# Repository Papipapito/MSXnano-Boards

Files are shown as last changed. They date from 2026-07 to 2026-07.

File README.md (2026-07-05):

# MSXnano · Boards

**Proof-of-concept carrier boards for the [MSXnano](https://github.com/Papipapito/MSXnano) project (Sipeed Tang Nano 20K).**
**Placas portadoras de prueba de concepto para el proyecto [MSXnano](https://github.com/Papipapito/MSXnano) (Sipeed Tang Nano 20K).**

*(English below · Español debajo)*

📄 Rich readme / readme enriquecido: [`README.html`](README.html)

### Gallery / Galería

| | |
|:---:|:---:|
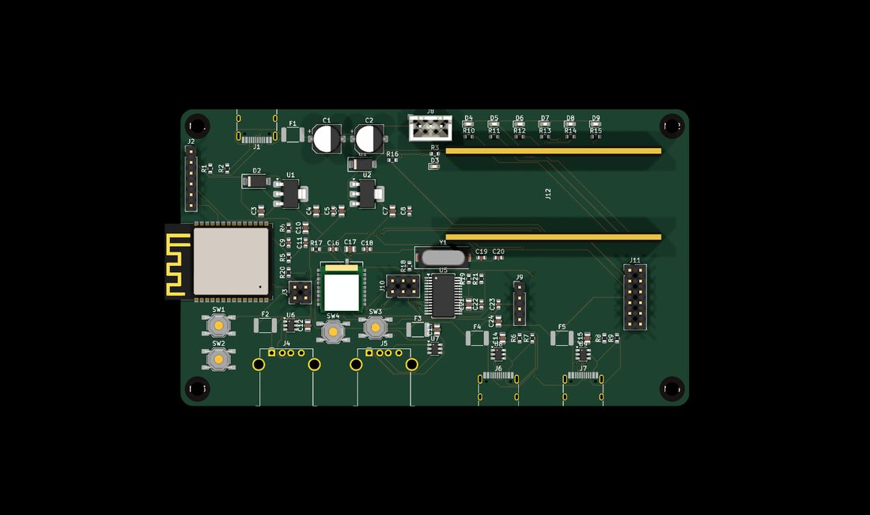
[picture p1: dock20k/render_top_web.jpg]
Top-down 3D
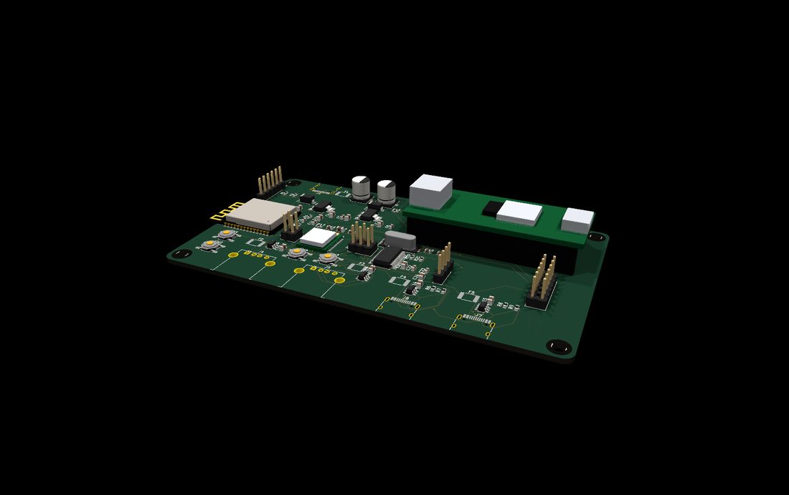
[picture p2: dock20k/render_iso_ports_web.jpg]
Assembled
|  |  |
| *Top-down 3D · Cenital 3D* | *Tang mounted on the socket · Tang montado en el zócalo* |
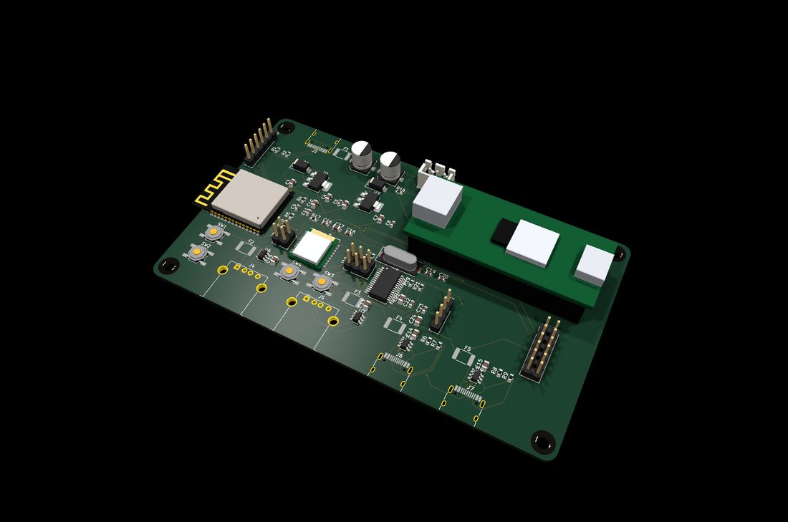
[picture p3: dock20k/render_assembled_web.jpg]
Assembled iso
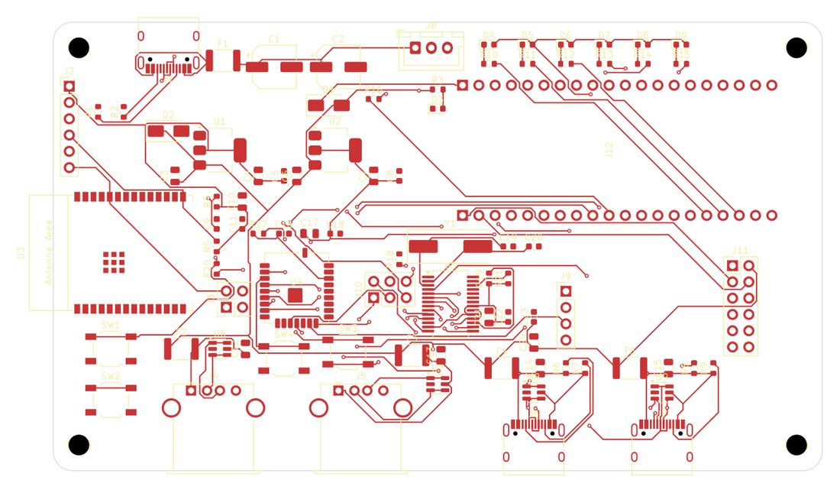
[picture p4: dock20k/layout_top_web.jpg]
KiCad top copper
|  |  |
| *Assembled · Montado* | *Top copper in KiCad (routing) · Cobre superior en KiCad (rutado)* |

More views in [`dock20k/`](dock20k/): full-res renders, front elevation, bottom copper, schematic & PCB PDFs.
*Más vistas en [`dock20k/`](dock20k/): renders a resolución completa, alzado frontal, cobre inferior, PDFs de esquemático y PCB.*

---

## 🇬🇧 English

These are **proof-of-concept boards built around the Sipeed M0S (BL616)** module. They exist for one exact reason:

> Since **~February 2024**, Sipeed ships Tang Nano 20K boards (silk-marked **`3921`**) whose **on-board BL616** has its **secure-boot eFuse in a state that often prevents it from running the FPGA-Companion firmware**. When that happens, the **USB keyboard and mouse stop working** (HDMI and the on-screen menu still work — that part is the FPGA, not the BL616). Sipeed's official workaround is to use an **external M0S Dock**.

Instead of hanging an external dock off the board with loose wires, these boards **integrate a dedicated M0S (BL616)** as the USB companion — plus a USB hub and WiFi — onto a single carrier, so **everything runs through the Tang's 2×20 headers with no external cables**.

### Boards

| Board | What it is | Status |
|---|---|---|
| [**dock20k**](dock20k/) | Tang Nano 20K carrier: **M0S (BL616)** companion + **FE1.1s** 4-port USB hub (2×USB-A + 2×USB-C) + **ESP32-C6** WiFi (UNAPI). Single USB-C power in. | Schematic ERC 0 · PCB routed (DRC 0) · **not yet fabricated** |
| [**rpi3-compatible**](rpi3-compatible/) | **Raspberry Pi 3 form factor (85×56 mm, 4-layer).** Fully modular: plug-in **Raspberry Pi Pico (RP2040)** USB companion + **ESP-01S** WiFi + **FE1.1s** hub. No soldered BL616/ESP32 — nothing exotic to source. | PCB routed (DRC 0 electrical) · **JLCPCB fab package ready** · not fabricated |

### rpi3-compatible highlights

- **Plug-in Raspberry Pi Pico (RP2040)** as the USB-HID companion, running the FPGA-Companion **`PICO`** build over the same `m0s[]` SPI path — **no RTL changes**, and it sidesteps the Tang `3921` BL616 secure-boot issue entirely (there is no on-board BL616).
- **ESP-01S** for WiFi on the core's **859372 bps** UART. Both the Pico and the ESP are **modules on sockets** — trivial to source, replace, or reflash.
- **Raspberry Pi 3 outline** (85 × 56 mm, RPi3 mounting pattern), **4 copper layers**, routed 100 % with GND planes. Ships with a **complete JLCPCB fab package** (gerbers + BOM + CPL, rotation-corrected).
- Details & key parts: [`rpi3-compatible/README.md`](rpi3-compatible/README.md).

### dock20k highlights

- **M0S (BL616)** runs the stock [FPGA-Companion](https://github.com/MiSTle-Dev/FPGA-Companion) `M0S_DOCK` build over the external `m0s[]` SPI path — **no RTL changes** to the MSXnano core.
- **ESP32-C6-WROOM-1-N8** for internet, running ducasp's [ESP32-UNAPI firmware](https://github.com/ducasp/ESP32-UNAPI-Firmware). It's the C6 (not the classic WROOM) because the core fixes the WiFi UART at **859372 bps**, a rate that is unreliable on the WROOM but fine on the C6.
- Everything routed through the **Tang's own 2×20 headers** — no external cables. Free Tang pins are broken out on an expansion header for future add-ons (e.g. MSX-MIDI).
- Connector & jumper reference: [`dock20k/CONNECTORS.md`](dock20k/CONNECTORS.md).

> ⚠️ **Proof of concept.** Designed and routed in KiCad but **not manufactured or tested in hardware yet.** Before ordering, verify the Tang socket against a physical board (rows at 20.32 mm, pin-1 position).

---

## 🇪🇸 Español

Estas son **placas de prueba de concepto construidas alrededor del módulo Sipeed M0S (BL616)**. Existen por una razón exacta:

> Desde **~febrero de 2024**, Sipeed fabrica placas Tang Nano 20K (marcadas **`3921`** en la serigrafía) cuyo **BL616 de a bordo** tiene el eFuse de **secure-boot en un estado que a menudo le impide ejecutar el firmware FPGA-Companion**. Cuando eso pasa, **el teclado y el ratón USB dejan de funcionar** (el HDMI y el menú en pantalla sí van — eso lo hace la FPGA, no el BL616). La solución oficial de Sipeed es usar un **M0S Dock externo**.

En lugar de colgar un dock externo con cables sueltos, estas placas **integran un M0S (BL616) dedicado** como companion USB —además de un hub USB y WiFi— en una sola portadora, de modo que **todo funciona por los conectores 2×20 del Tang, sin cables externos**.

### Placas

| Placa | Qué es | Estado |
|---|---|---|
| [**dock20k**](dock20k/) | Portadora del Tang Nano 20K: companion **M0S (BL616)** + hub USB **FE1.1s** de 4 puertos (2×USB-A + 2×USB-C) + WiFi **ESP32-C6** (UNAPI). Entrada única de 5 V por USB-C. | Esquemático ERC 0 · PCB rutada (DRC 0) · **sin fabricar aún** |
| [**rpi3-compatible**](rpi3-compatible/) | **Formato Raspberry Pi 3 (85×56 mm, 4 capas).** Totalmente modular: **Raspberry Pi Pico (RP2040)** enchufable como companion USB + **ESP-01S** WiFi + hub **FE1.1s**. Sin BL616/ESP32 soldados — nada raro que abastecer. | PCB rutada (DRC 0 eléctricos) · **paquete de fabricación JLCPCB listo** · sin fabricar |

### Claves de rpi3-compatible

- **Raspberry Pi Pico (RP2040) enchufable** como companion USB-HID, con el build **`PICO`** de FPGA-Companion por la misma ruta SPI `m0s[]` — **sin tocar el RTL**, y esquiva por completo el problema del secure-boot del BL616 de los Tang `3921` (aquí no hay BL616).
- **ESP-01S** para WiFi en la UART del core a **859372 bps**. Tanto el Pico como el ESP son **módulos en zócalos** — fáciles de abastecer, sustituir o reflashear.
- **Contorno Raspberry Pi 3** (85 × 56 mm, patrón de anclajes RPi3), **4 capas de cobre**, rutada al 100 % con planos de GND. Incluye un **paquete de fabricación JLCPCB completo** (gerbers + BOM + CPL, con rotaciones corregidas).
- Detalles y piezas clave: [`rpi3-compatible/README.md`](rpi3-compatible/README.md).

### Claves de dock20k

- El **M0S (BL616)** ejecuta el build `M0S_DOCK` de [FPGA-Companion](https://github.com/MiSTle-Dev/FPGA-Companion) tal cual, por la ruta SPI externa `m0s[]` — **sin tocar el RTL** del core MSXnano.
- **ESP32-C6-WROOM-1-N8** para internet, con el [firmware ESP32-UNAPI](https://github.com/ducasp/ESP32-UNAPI-Firmware) de ducasp. Es el C6 (no el WROOM clásico) porque el core fija la UART del WiFi a **859372 bps**, una velocidad poco fiable en el WROOM pero correcta en el C6.
- Todo enrutado por los **conectores 2×20 del propio Tang** — sin cables externos. Los pines libres del Tang salen a un cabezal de expansión para futuras ampliaciones (p. ej. MSX-MIDI).
- Referencia de conectores y jumpers: [`dock20k/CONNECTORS.md`](dock20k/CONNECTORS.md).

> ⚠️ **Prueba de concepto.** Diseñada y rutada en KiCad pero **aún no fabricada ni probada en hardware.** Antes de encargarla, verifica el zócalo del Tang contra una placa física (filas a 20.32 mm, posición del pin 1).

---

### Credits / Créditos

Board design: **Papipapito**. Third-party footprints/3D models (Sipeed M0S, Espressif ESP32-C6) keep their own licenses. BL616 firmware: [FPGA-Companion](https://github.com/MiSTle-Dev/FPGA-Companion) (MiSTle-Dev). WiFi firmware: [ESP32-UNAPI](https://github.com/ducasp/ESP32-UNAPI-Firmware) (ducasp).

*Diseño de la placa: **Papipapito**. Las huellas/modelos 3D de terceros conservan su licencia. Firmware BL616: FPGA-Companion. Firmware WiFi: ESP32-UNAPI de ducasp.*

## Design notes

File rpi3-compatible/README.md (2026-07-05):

# rpi3-compatible

**MSXnano carrier in Raspberry Pi 3 form factor (85 × 56 mm), fully modular.**
**Placa portadora MSXnano con formato Raspberry Pi 3 (85 × 56 mm), totalmente modular.**

Instead of soldering the USB companion and WiFi chips (like [`../dock20k`](../dock20k/)), this board takes **plug-in modules**: a **Raspberry Pi Pico (RP2040)** as the USB-HID companion and an **ESP-01S** for WiFi — so there is nothing exotic to source or reflow, and the RPi3 outline drops into any Pi-3 case/mount.

En lugar de soldar los chips de companion USB y WiFi (como en [`../dock20k`](../dock20k/)), esta placa usa **módulos enchufables**: una **Raspberry Pi Pico (RP2040)** como companion USB-HID y un **ESP-01S** para WiFi — así no hay nada raro que abastecer ni soldar, y el contorno RPi3 encaja en cualquier caja/soporte de Pi 3.

### Views / Vistas

| | |
|:---:|:---:|
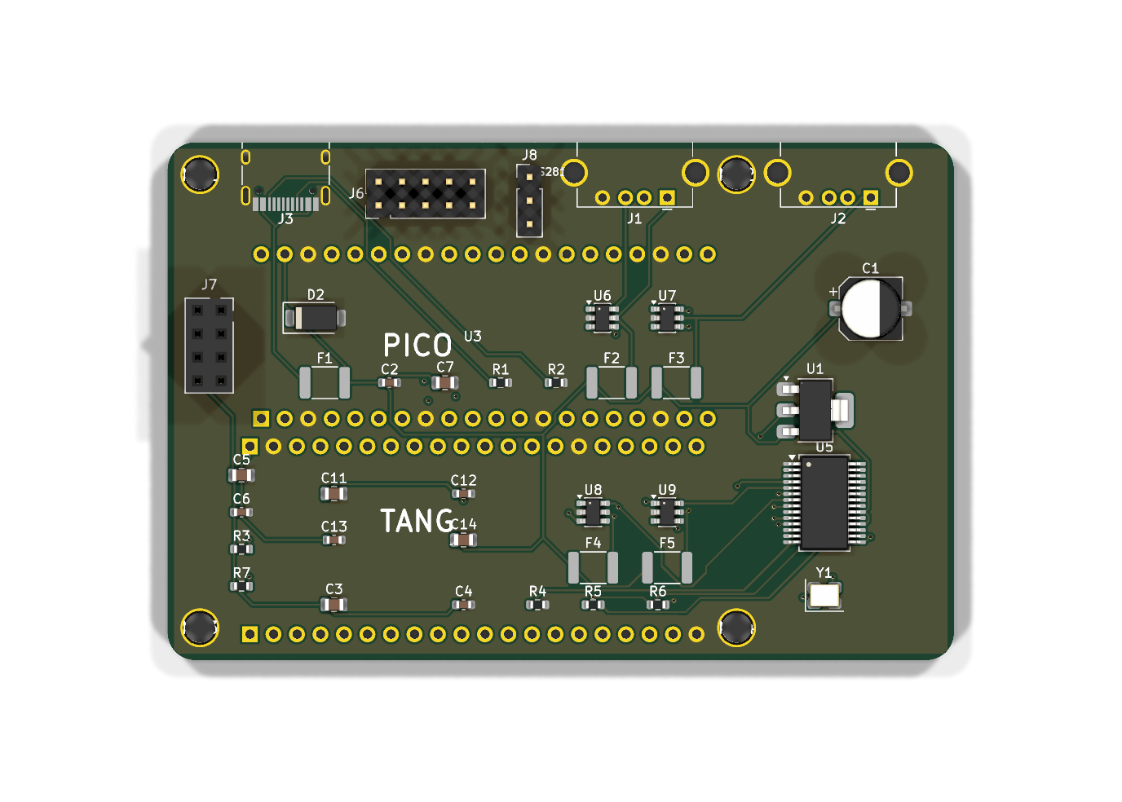
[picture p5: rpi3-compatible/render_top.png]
3D top
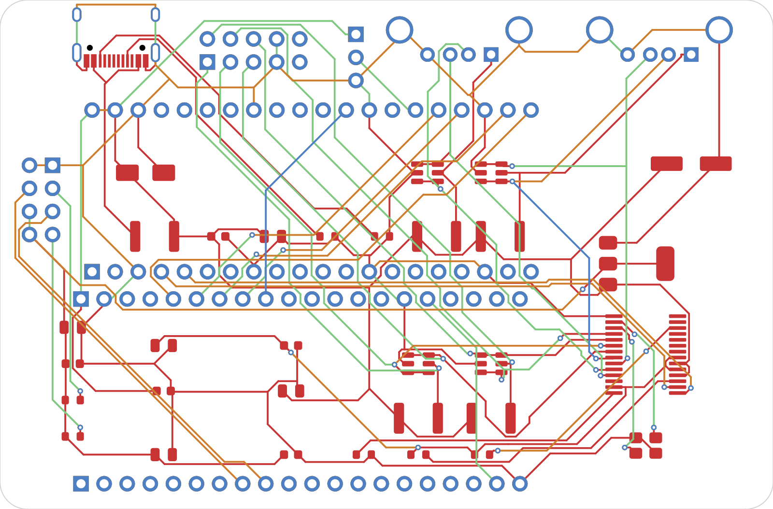
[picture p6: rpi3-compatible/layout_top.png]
Top copper
|  |  |
| *3D top (as placed) · 3D cenital (colocación real)* | *4-layer routing · Rutado 4 capas* |

PDFs: [schematic](board8020_schematic.pdf) · [PCB top](board8020_pcb_top.pdf) · 3D: [`board8020_rpi3.step`](board8020_rpi3.step)

```
USB-C 5V ──fuse 2A──► +5V ──► Tang 5V (socket) + Pico VSYS
                       ├──► AMS1117-3.3 ──► ESP-01S (WiFi)
                       └──► FE1.1s hub ──► 4 downstream ports (500 mA polyfuse each)

Tang (2x20 socket) ──SPI (M0S_* nets)──► RPi Pico (FPGA-Companion PICO build) ──USB host──► FE1.1s hub ──► 2×USB-A + USB2 header
                   ──UART 27/28──► ESP-01S UART @ 859372 bps
Pico GP20 ──► WS2812 header (J8, DIN)
```

## EN — Design notes

- **USB companion = plug-in Raspberry Pi Pico (RP2040)** on a 2×20 female socket, running the FPGA-Companion **`PICO`** build (PIO-USB host). Drives keyboard/mouse/joystick over the same SPI `m0s[]` path the core already detects — **no RTL changes**. Avoids the Tang `3921` BL616 secure-boot problem entirely (no on-board BL616 involved).
- **WiFi = ESP-01S** on a 2×4 female socket, on the core's WiFi UART @ **859372 bps** (its own 3.3 V LDO + pull-ups).
- **Hub = FE1.1s** (SSOP-28) with a **12 MHz SMD-3225 crystal** (JLC Basic C9002). Downstream: 2× USB-A on the rear edge + a **2×5 USB2 header** (2 more ports).
- **Form factor:** exact **Raspberry Pi 3** outline — 85 × 56 mm, 4 mounting holes on the RPi3 58 × 49 pattern. **4 copper layers.**
- **Header-only parts:** the USB2 header (J6), the ESP-01 socket (J7) and the **WS2812 3-pin header (J8)** are left as **plated holes** — solder your own. They are **excluded from the assembly BOM**.

## ES — Notas de diseño

- **Companion USB = Raspberry Pi Pico (RP2040) enchufable** en zócalo 2×20 hembra, con el build **`PICO`** de FPGA-Companion (host USB por PIO). Lleva teclado/ratón/joystick por la misma ruta SPI `m0s[]` que el core ya detecta — **sin tocar el RTL**. Evita por completo el problema del secure-boot del BL616 de los Tang `3921` (aquí no hay BL616).
- **WiFi = ESP-01S** en zócalo 2×4 hembra, en la UART de WiFi del core a **859372 bps** (con su LDO de 3.3 V y pull-ups).
- **Hub = FE1.1s** (SSOP-28) con **cristal 12 MHz SMD-3225** (JLC Basic C9002). Downstream: 2× USB-A en el borde trasero + un **header USB2 2×5** (2 puertos más).
- **Formato:** contorno exacto de **Raspberry Pi 3** — 85 × 56 mm, 4 anclajes en el patrón RPi3 58 × 49. **4 capas de cobre.**
- **Piezas solo-agujeros:** el header USB2 (J6), el zócalo del ESP-01 (J7) y el **header WS2812 de 3 pines (J8)** quedan como **agujeros metalizados** — los sueldas tú. Están **fuera del BOM de montaje**.

## Status / Estado

- EN: 85 × 56 mm **4-layer PCB, routed 100 %** with freerouting, GND planes on all 4 layers. **DRC: 0 unconnected, 0 electrical errors** (only cosmetic silk/library warnings). **JLCPCB fabrication package included** (gerbers + BOM + CPL). Component placement done by hand. **Not fabricated yet** — before ordering, verify the USB-A (J1/J2) and USB-C (J3) footprints/orientation and the Pico/Tang socket rows against physical modules.
- ES: PCB de **4 capas 85 × 56 mm, rutada al 100 %** con freerouting, planos de GND en las 4 capas. **DRC: 0 sin conectar, 0 errores eléctricos** (solo avisos cosméticos de serigrafía/librería). **Paquete de fabricación JLCPCB incluido** (gerbers + BOM + CPL). Colocación de componentes hecha a mano. **Sin fabricar aún** — antes de encargarla, verifica los footprints/orientación de los USB-A (J1/J2) y USB-C (J3) y las filas de los zócalos Pico/Tang contra los módulos físicos.

## Files / Ficheros

`msxnano-board8020.kicad_pro/.kicad_sch/.kicad_pcb` · `sym-lib-table` / `fp-lib-table` (paths via `${KIPRJMOD}`) · `libs/` (M0S + Espressif symbols/footprints/3D, FE1.1s + Tang/Pico sockets custom) · `board8020_schematic.pdf` · `board8020_pcb_top.pdf` · `board8020_rpi3.step` · **fab:** `board8020_gerbers.zip` · `board8020_BOM_jlcpcb.csv` · `board8020_CPL_jlcpcb.csv` (JLCPCB format, top side, rotation-corrected).

## Key parts / Piezas clave (JLCPCB LCSC)

FE1.1s hub `C9359` (SSOP-28) · AMS1117-3.3 `C6186` · USBLC6-2SC6 ESD `C2687116` ×4 · 12 MHz 3225 xtal `C9002` (Basic) · SMAJ5.0A TVS `C2925443` · USB-C `C165948` · USB-A horiz `C2345` ×2 · 10k `C98220` · 5.1k `C23186` · 2.7k `C13167` · PPTC 2A `C960026` / 500mA `C369168`. **Not assembled (holes only):** RPi Pico, Tang Nano 20K, ESP-01S socket, USB2 header, WS2812 header.

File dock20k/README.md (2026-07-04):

# dock20k

Carrier / dock board for the **Tang Nano 20K** running the **MSXnano** core.
Placa portadora ("dock") para el **Tang Nano 20K** con el core **MSXnano**.

📖 See [`CONNECTORS.md`](CONNECTORS.md) for the full connector/jumper reference · [`../README.html`](../README.html) for the illustrated bilingual overview.

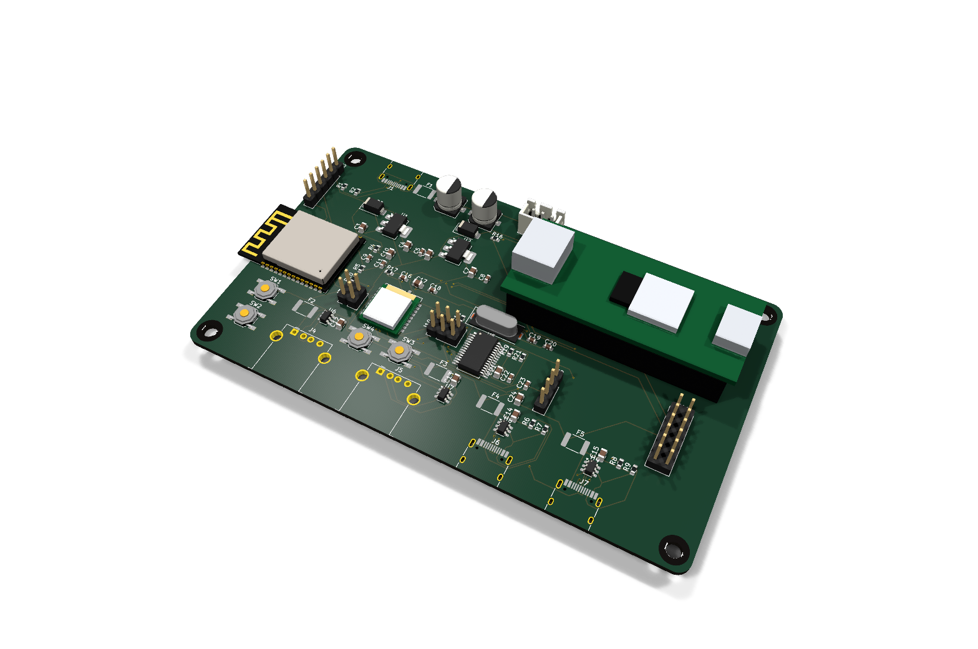
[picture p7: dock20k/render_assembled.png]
Assembled render


### Views / Vistas

| | |
|:---:|:---:|
| Top-down | Low angle |
| *Top-down 3D · Cenital 3D* | *Tang on socket · Tang en zócalo* |
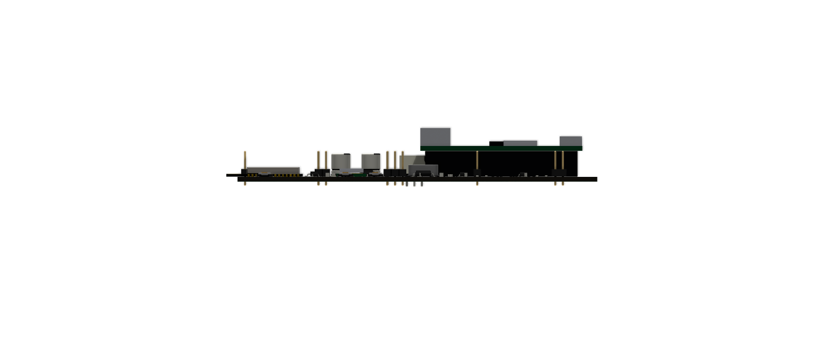
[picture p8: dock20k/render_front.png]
Front elevation
| KiCad top copper |  |
| *Top copper routing (KiCad) · Rutado cobre superior* | *Front elevation of the stack · Alzado del stack* |

Full-res: [`render_top.png`](render_top.png) · [`render_iso_ports.png`](render_iso_ports.png) · [`render_dock.png`](render_dock.png) · [`layout_top.png`](layout_top.png) · [`layout_bottom.png`](layout_bottom.png) · PDFs: [schematic](msxnano_dock_schematic.pdf) · [PCB top](msxnano_dock_pcb_top.pdf) / [bottom](msxnano_dock_pcb_bottom.pdf)

```
USB-C 5V ──fuse 2A──► +5V ──SS34──► Tang 5V pin (J5.1)
                       ├──► AMS1117-3.3 #1 ──► ESP32-C6
                       ├──► AMS1117-3.3 #2 ──► M0S / BL616
                       └──► FE1.1s hub + 4 ports (500 mA polyfuse each)

Tang (2x20 socket) ──SPI 42/41/56/54/51──► M0S BL616 ──USB──► FE1.1s hub ──► 2×USB-A + 2×USB-C
                   ──UART 27/28──► ESP32-C6 UART0 @ 859372 bps
                   ──pin 25──► WS2812   ──pins 15-20──► status LEDs   ──pin 26──► ESP reset (R20 0Ω)
```

## EN — Design notes

- **BL616 = bare Sipeed M0S module** (soldered). Runs the stock FPGA-Companion `M0S_DOCK` build — SPI on IO10–IO14 exactly like the dock, detected by the core via `m0s[2]`. No RTL changes. The M0S has **no on-board regulator** → dedicated 3.3 V LDO.
- **Hub = FE1.1s** (SSOP-28): 12 MHz crystal (load caps integrated), REXT 2.7 kΩ 1%, self-powered (BUSJ→3V3, **OVCJ→10k to 3V3, mandatory**, PWRJ NC). Note: the Rev 1.0 datasheet misprints DMU as pin 25 — it is **pin 15**.
- **WiFi = ESP32-C6-WROOM-1-N8** with ducasp's ESP32-UNAPI firmware. The core's WiFi UART is fixed at **859372 bps**; ducasp reports that rate is unreliable on the classic WROOM but fine on the C6 (the repo's default target). Needs **8 MB flash** → the -N8 part.
- **Rule:** everything goes through the Tang's two 2×20 headers — **no external cables.**

## ES — Notas de diseño

- **BL616 = módulo Sipeed M0S pelado** (soldado). Ejecuta el build `M0S_DOCK` de FPGA-Companion tal cual — SPI en IO10–IO14 igual que el dock, detectado por el core vía `m0s[2]`. Sin tocar RTL. El M0S **no lleva regulador** → LDO de 3.3 V dedicado.
- **Hub = FE1.1s** (SSOP-28): cristal 12 MHz (caps de carga integrados), REXT 2.7 kΩ 1%, self-powered (BUSJ→3V3, **OVCJ→10k a 3V3, obligatorio**, PWRJ sin conectar). Ojo: el datasheet Rev 1.0 imprime mal DMU como pin 25 — es el **pin 15**.
- **WiFi = ESP32-C6-WROOM-1-N8** con el firmware ESP32-UNAPI de ducasp. La UART del WiFi del core está fija a **859372 bps**; ducasp indica que esa velocidad es poco fiable en el WROOM clásico pero correcta en el C6 (target por defecto del repo). Necesita **8 MB de flash** → la variante -N8.
- **Regla:** todo pasa por los dos conectores 2×20 del Tang — **sin cables externos.**

## Status / Estado

- EN: Schematic complete (**ERC 0 errors**). 2-layer PCB, **routed 100%** with freerouting (**DRC 0 errors**), GND pours both sides, RF keepout under the ESP antenna. **Not fabricated yet** — verify the socket against a real Tang (rows 20.32 mm, pin-1 side) before ordering.
- ES: Esquemático completo (**ERC 0 errores**). PCB de 2 capas, **rutada al 100%** con freerouting (**DRC 0 errores**), planos de GND en ambas caras, keepout de RF bajo la antena del ESP. **Sin fabricar aún** — verifica el zócalo contra un Tang real (filas 20.32 mm, lado del pin 1) antes de encargarla.

## Files / Ficheros

`msxnano_dock.kicad_pro/.kicad_sch/.kicad_pcb` · `sym-lib-table` / `fp-lib-table` (paths via `${KIPRJMOD}`) · `libs/` (M0S + Espressif official symbols/footprints/3D, FE1.1s + Tang socket custom) · `msxnano_dock_schematic.pdf` · `msxnano_dock_pcb_top.pdf` / `_bottom.pdf` · `msxnano_dock_bom.csv` · `render_dock.png` / `render_assembled.png`

## Sources / Fuentes (verified 2026-07)

Tang Nano 20K official 3921 schematic + dimensions (dl.sipeed.com) · M0S module & dock schematics + official KiCad footprint · FE1.1s datasheet Rev B (DMU = pin 15) · ESP32-UNAPI source (UART0, baud, 8 MB, targets).

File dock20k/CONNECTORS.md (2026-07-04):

# dock20k — Connectors / Conectores (J1–J12)

Reference for every connector and jumper: what it is, its pinout and what to use it for.
Reader-friendly HTML version: [`../README.html`](../README.html).

Referencia de todos los conectores y jumpers: qué son, su pinout y para qué usarlos.
Versión HTML más cómoda de leer: [`../README.html`](../README.html).

> Pin numbers match the PCB silkscreen (pin 1 has a square pad). On 2-row connectors,
> the odd column is 1/3/5… and the even column is 2/4/6….
> **[cap]** = a 2.54 mm jumper. "Bridge A-B" = place a cap over pins A and B.
>
> Los números de pin coinciden con la serigrafía (el pin 1 lleva pad cuadrado). En los
> conectores de 2 filas, la columna impar es 1/3/5… y la par 2/4/6….
> **[cap]** = puente de 2.54 mm. "Puentear A-B" = colocar un cap sobre los pines A y B.

---

## Summary / Resumen

| Ref | Silk | Type / Tipo | Use / Uso | Jumper? |
|-----|---|---|---|---|
| **J1**  | USB-C_POWER | USB-C recept. | 5 V power in / entrada 5 V (+ BL616 flash data) | — |
| **J2**  | ESP_FLASH | 1×6 header | Program the ESP32-C6 / programar el ESP32-C6 | — |
| **J3**  | ESP_UART_LINK | 2×2 | Connect/isolate FPGA↔ESP UART / conectar-aislar UART | **Yes (2)** |
| **J4**  | USB-A_1 | USB-A recept. | USB output port / puerto USB de salida | — |
| **J5**  | USB-A_2 | USB-A recept. | USB output port / puerto USB de salida | — |
| **J6**  | USB-C_1 | USB-C recept. | USB output port / puerto USB de salida | — |
| **J7**  | USB-C_2 | USB-C recept. | USB output port / puerto USB de salida | — |
| **J8**  | WS2812_STRIP  | JST-XH 1×3 | WS2812 LED strip / tira de LEDs WS2812 | — |
| **J9**  | BL616_FLASH | 1×4 header | BL616 serial log + emergency flash | — |
| **J10** | BL_USB_SEL | 2×3 | Route BL616 USB: hub vs flash / enrutar USB del BL616 | **Yes (2)** |
| **J11** | EXPANSION | 2×6 | Free Tang pins + power / pines libres del Tang | — |
| **J12** | TangNano20K | 2×20 socket | Where the Tang plugs in / donde se enchufa el Tang | — |

Buttons / Pulsadores: **SW1** = ESP reset, **SW2** = ESP boot, **SW3** = BL616 boot, **SW4** = BL616 reset.

---

## The two config jumpers / Los dos jumpers de configuración

### J3 — ESP_UART_LINK (FPGA ↔ ESP32 serial link / enlace serie)

```
 row1   1 FPGA_TX  ──  2 ESP_RX0     [cap 1-2]
 row2   3 ESP_TX0  ──  4 FPGA_RX     [cap 3-4]
```

- **EN — Normal (WiFi working):** both caps on (1-2 and 3-4). ESP and core talk at 859372 bps.
  **To flash the ESP:** remove both caps, so the FPGA lines don't fight the USB-serial adapter on J2.
- **ES — Normal (WiFi funcionando):** los dos caps puestos (1-2 y 3-4). ESP y core hablan a 859372 bps.
  **Para flashear el ESP:** quita los dos caps, para que las líneas de la FPGA no peleen con el adaptador USB-serie de J2.

### J10 — BL_USB_SEL (where the BL616's single USB goes / a dónde va el único USB del BL616)

```
          D+ column        D- column
 row1   1 HUB_UP_DP      2 HUB_UP_DM     → to the USB hub (normal / normal)
 row2   3 BL_USB_DP      4 BL_USB_DM     → BL616 USB (common / común)
 row3   5 PC_DP          6 PC_DM         → J1 data lines (flashing / flasheo)
```

- **EN — Normal (keyboard/mouse via hub):** caps on **1-3 and 2-4** (BL616 → hub). Default position.
  **To flash the BL616:** move caps to **3-5 and 4-6** (BL616 → J1), then plug a USB-C **data** cable from J1 to the PC.
- **ES — Normal (teclado/ratón por el hub):** caps en **1-3 y 2-4** (BL616 → hub). Posición por defecto.
  **Para flashear el BL616:** mueve los caps a **3-5 y 4-6** (BL616 → J1), y conecta un cable USB-C **de datos** de J1 al PC.

---

## Programming headers / Cabeceras de programación

### J2 — ESP_FLASH (1×6) — program the ESP32-C6 / programar el ESP32-C6

```
 1  +3V3   ESP logic (don't connect if already USB-C powered) / lógica del ESP (no conectar si ya alimentas por USB-C)
 2  GND
 3  EN     ESP reset  → adapter RTS (or SW1) / reset del ESP → RTS (o SW1)
 4  BOOT   GPIO9      → adapter DTR (or SW2) / arranque → DTR (o SW2)
 5  TX0    GPIO16     → adapter RX
 6  RX0    GPIO17     → adapter TX
```
Remove J3 caps before flashing here. / Quita los caps de J3 antes de flashear por aquí.
After the first flash, the firmware updates over WiFi (OTA) or via the MSX link.
Tras el primer flasheo, el firmware se actualiza por WiFi (OTA) o por el enlace MSX.

### J9 — BL616_FLASH (1×4) — log + emergency flash / log + flasheo de emergencia

```
 1  +3V3
 2  GND
 3  TX     BL616 GPIO21  → adapter RX   (serial log 115200 8N1 / log serie 115200 8N1)
 4  RX     BL616 GPIO22  → adapter TX
```

---

## Power & outputs / Alimentación y salidas

- **J1 — USB-C_POWER.** EN: powers the whole board and the Tang (via its 5 V pin, through an SS34 blocking diode); its data lines feed J10 (used only when flashing the BL616). · ES: alimenta toda la placa y el Tang (por su pin de 5 V, con diodo SS34 anti-retorno); sus líneas de datos van a J10 (solo se usan al flashear el BL616).
- **J4 / J5 (USB-A) · J6 / J7 (USB-C).** EN: the four USB output ports of the FE1.1s hub — keyboard, mouse, joypad, flash drive. Each has a 500 mA polyfuse + ESD. USB-C ports act as host (56 k Rp). · ES: los cuatro puertos USB de salida del hub FE1.1s — teclado, ratón, joypad, pendrive. Cada uno con polyfuse de 500 mA + ESD. Los USB-C actúan como host (Rp 56 k).
- **J8 — WS2812_STRIP (JST 1×3):** `1=+5V, 2=DIN (Tang pin 25 via 330 Ω), 3=GND`. EN: addressable LED strip (case). · ES: tira de LEDs direccionables (caja).

### J11 — EXPANSION (2×6) — free Tang pins / pines libres del Tang

```
 odd column (left)      even column (right)
 1  3V3 (Tang)          2  +5V
 3  P73                 4  P74
 5  P77                 6  P29
 7  P30                 8  P31
 9  P72                10  P71
11  GND                12  GND
```
EN: unused FPGA balls + power, for future add-ons (e.g. MSX-MIDI) without redesigning the board. Assign a new signal in the core's `.cst` to one of these pins.
ES: balls de la FPGA sin usar + alimentación, para ampliaciones futuras (p. ej. MSX-MIDI) sin rediseñar la placa. Asigna la señal nueva en el `.cst` del core a uno de estos pines.

### J12 — TangNano20K socket / zócalo

EN: not a jumper — the 2×20 **female socket where the Tang Nano 20K plugs in**. Every signal between board and Tang passes through here (no loose wires). Rows 20.32 mm apart; row A is the 5 V side (per official 3921 schematic).
ES: no es un jumper — el **zócalo 2×20 hembra donde se enchufa el Tang Nano 20K**. Todas las señales entre placa y Tang pasan por aquí (sin cables sueltos). Filas a 20.32 mm; la fila A es la del pin de 5 V (según el esquemático oficial 3921).

---

## Recipes / Recetas

**1) Normal operation / Funcionamiento normal** — J3: both caps (1-2, 3-4) · J10: caps up (1-3, 2-4) · Tang in J12, power on J1, peripherals on J4–J7.

**2) Flash the ESP32-C6 / Flashear el ESP32-C6** — remove J3 caps · USB-UART on J2 (TX↔RX crossed) · hold **SW2 BOOT** + press **SW1 RST** · program, then restore J3 caps.

**3) Flash the BL616 / Flashear el BL616** — J10 caps to 3-5, 4-6 · USB-C data cable J1→PC · hold **SW3 BL_BOOT** + press **SW4 BL_RST** · load `fpga_companion_m0sdock.bin`, then restore J10 caps. (Alt: UART on J9.)

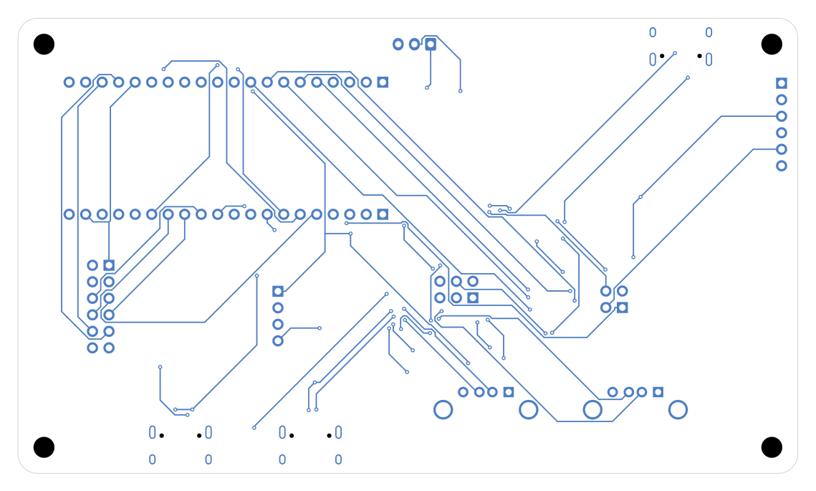
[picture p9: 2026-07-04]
dock20k/layout_bottom.png

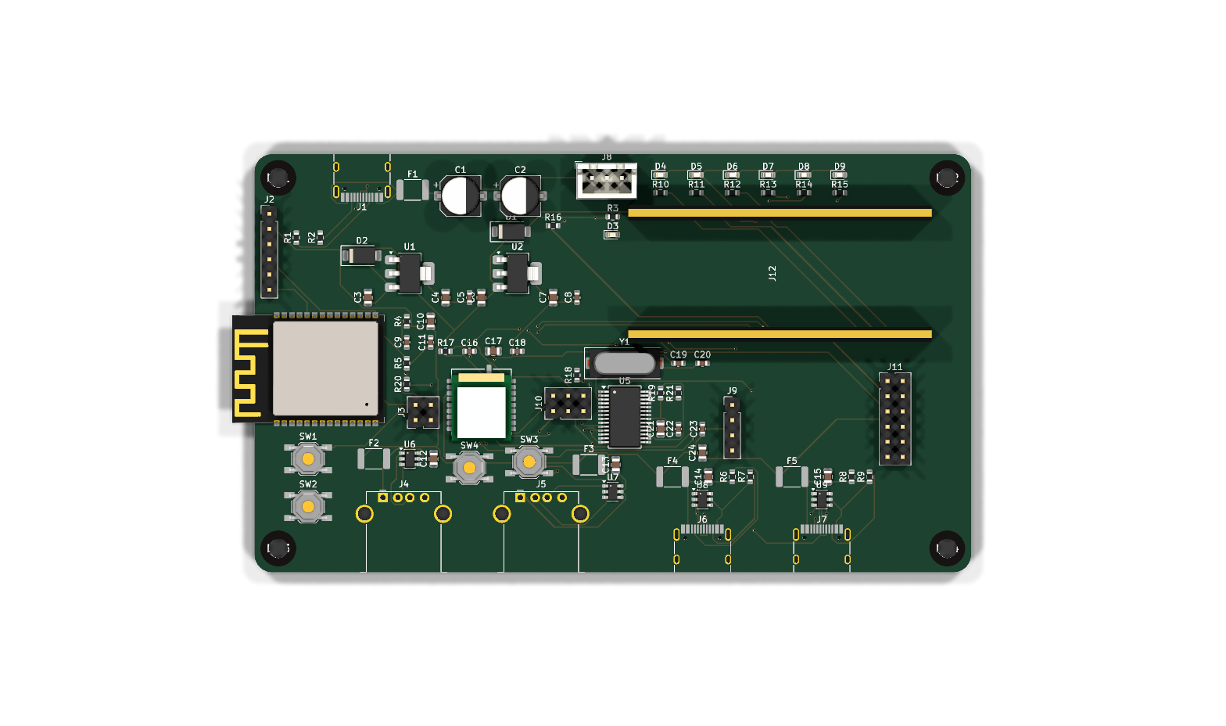
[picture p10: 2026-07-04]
dock20k/render_top.png

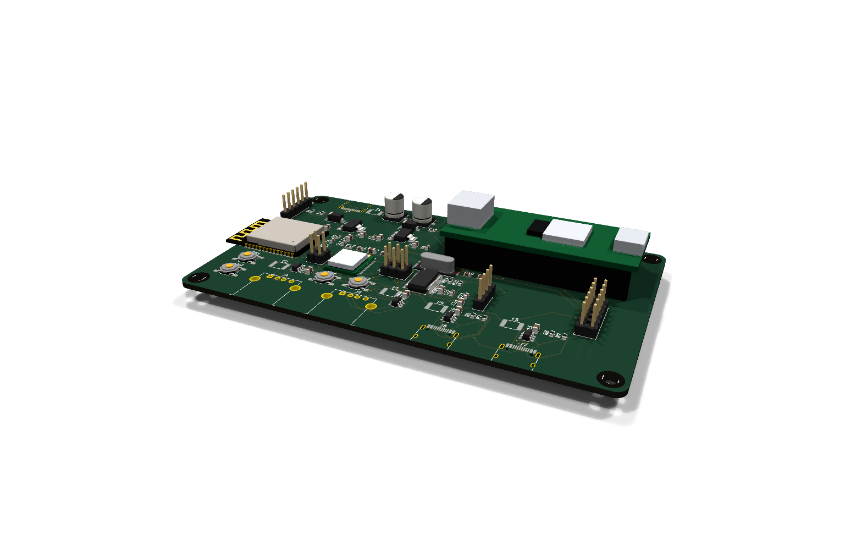
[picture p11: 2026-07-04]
dock20k/render_iso_ports.png

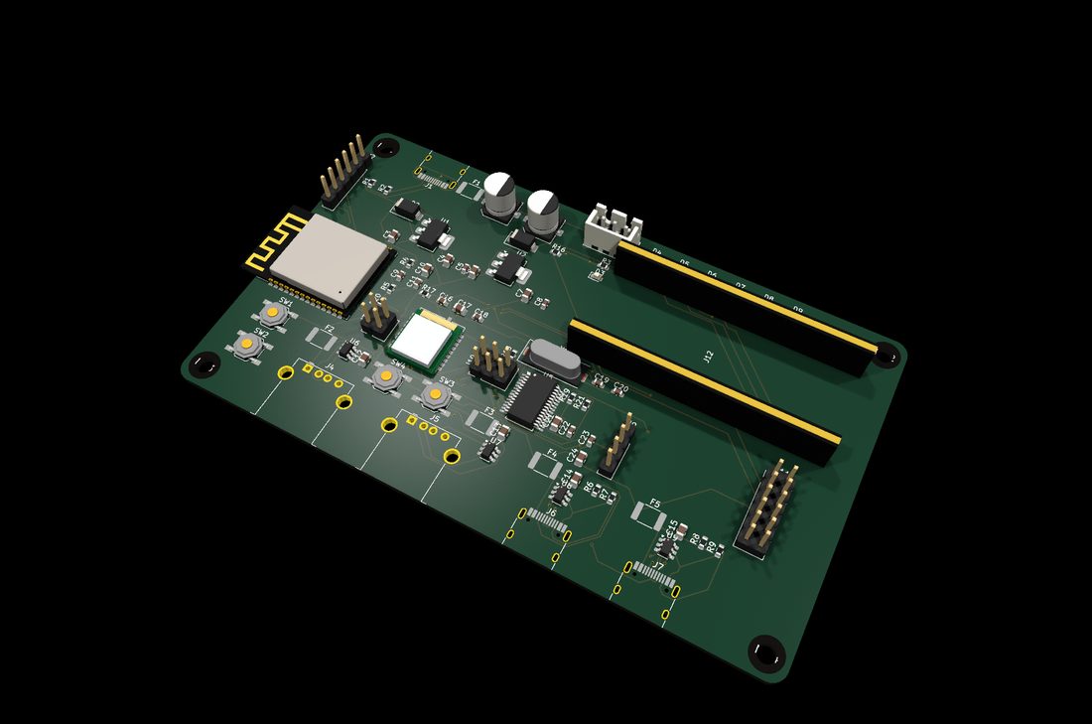
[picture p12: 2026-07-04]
dock20k/render_dock_web.jpg

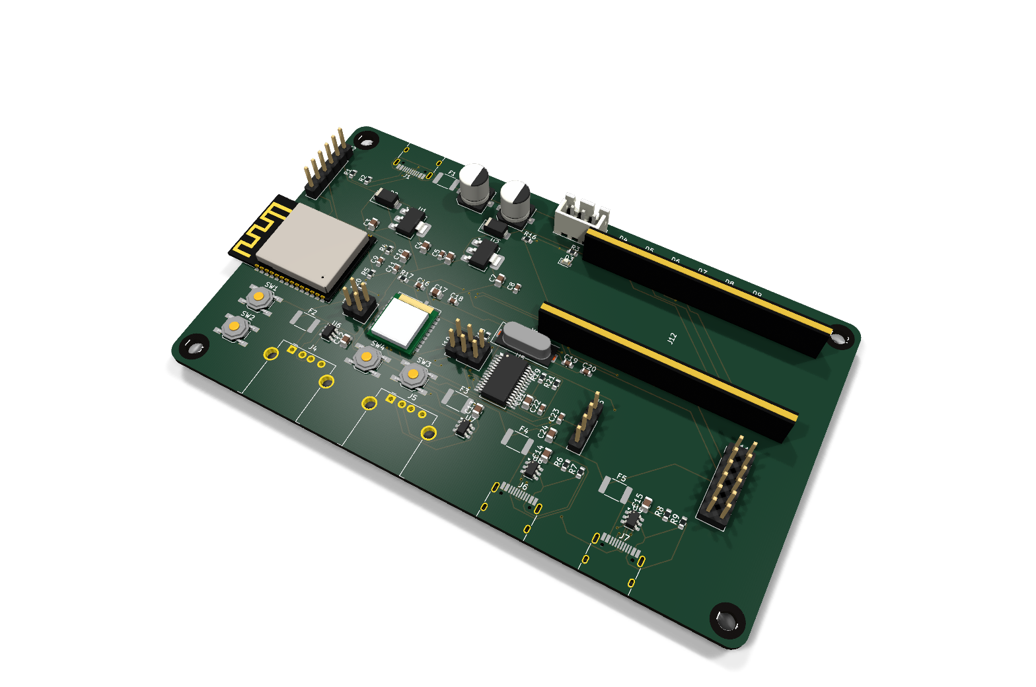
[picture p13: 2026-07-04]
dock20k/render_dock.png

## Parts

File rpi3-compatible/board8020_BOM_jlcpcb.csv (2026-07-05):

Comment | Designator | Footprint | LCSC Part #
5.1k 0603 1% | R1,R2 | R_0603 | C23186
10k 0603 1% | R3,R5,R6,R7 | R_0603 | C98220
2.7k 0603 1% | R4 | R_0603 | C13167
100nF 50V 0603 | C2,C4,C6,C12,C13 | C_0603 | C14663
10uF 25V 0805 | C5,C7,C11,C14 | C_0805 | C15850
22uF 25V 0805 | C3 | C_0805 | C45783
220uF 25V | C1 | CP_Elec_6.3x7.7 | C2918361
12MHz | Y1 | Crystal_SMD_3225-4Pin | C9002
AMS1117-3.3 | U1 | SOT-223 | C6186
FE1.1S | U5 | SSOP-28 | C9359
USBLC6-2SC6 | U6,U7,U8,U9 | SOT-23-6 | C2687116
SMAJ5.0A | D2 | D_SMA | C2925443
PPTC 2A | F1 | Fuse_1812 | C960026
PPTC 500mA | F2,F3,F4,F5 | Fuse_1812 | C369168
USB-C TYPE-C-31-M-12 | J3 | USB_C_HRO | C165948
USB-A hembra horiz 902-131A | J1,J2 | USB_A_horiz | C2345

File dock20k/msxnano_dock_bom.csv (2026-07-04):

value | footprint | quantity | references
12MHz | Crystal:Crystal_SMD_HC49-SD | 1 | ['Y1']
MountingHole_3.2mm | MountingHole:MountingHole_3.2mm | 4 | ['MH4', 'MH1', 'MH3', 'MH2']
LED2 | LED_SMD:LED_0603_1608Metric | 1 | ['D6']
1k | Resistor_SMD:R_0603_1608Metric | 7 | ['R17', 'R14', 'R11', 'R10', 'R13', 'R12', 'R15']
SS34 | Diode_SMD:D_SMA | 1 | ['D1']
EXPANSION | Connector_PinHeader_2.54mm:PinHeader_2x06_P2.54mm_Vertical | 1 | ['J11']
BL_USB_SEL | Connector_PinHeader_2.54mm:PinHeader_2x03_P2.54mm_Vertical | 1 | ['J10']
18pF (DNP) | Capacitor_SMD:C_0603_1608Metric | 2 | ['C19', 'C20']
2A | Fuse:Fuse_1812_4532Metric | 1 | ['F1']
330R | Resistor_SMD:R_0603_1608Metric | 1 | ['R16']
220uF/10V | Capacitor_SMD:CP_Elec_6.3x7.7 | 2 | ['C1', 'C2']
10uF | Capacitor_SMD:C_0805_2012Metric | 9 | ['C21', 'C13', 'C3', 'C15', 'C24', 'C12', 'C6', 'C14', 'C17']
ESP_RST | Button_Switch_SMD:SW_SPST_TL3342 | 1 | ['SW1']
22uF | Capacitor_SMD:C_0805_2012Metric | 3 | ['C10', 'C7', 'C4']
ESP_BOOT | Button_Switch_SMD:SW_SPST_TL3342 | 1 | ['SW2']
5k1 | Resistor_SMD:R_0603_1608Metric | 2 | ['R1', 'R2']
100nF | Capacitor_SMD:C_0603_1608Metric | 7 | ['C8', 'C16', 'C23', 'C22', 'C11', 'C18', 'C5']
SMAJ5.0A | Diode_SMD:D_SMA | 1 | ['D2']
56k | Resistor_SMD:R_0603_1608Metric | 4 | ['R9', 'R7', 'R6', 'R8']
LED1 | LED_SMD:LED_0603_1608Metric | 1 | ['D5']
LED3 | LED_SMD:LED_0603_1608Metric | 1 | ['D7']
FE1.1s | Package_SO:SSOP-28_5.3x10.2mm_P0.65mm | 1 | ['U5']
BL_RST | Button_Switch_SMD:SW_SPST_TL3342 | 1 | ['SW4']
TangNano20K | msxnano_dock:TangNano20K_Socket | 1 | ['J12']
PWR | LED_SMD:LED_0603_1608Metric | 1 | ['D3']
LED5 | LED_SMD:LED_0603_1608Metric | 1 | ['D9']
10k | Resistor_SMD:R_0603_1608Metric | 4 | ['R19', 'R4', 'R5', 'R21']
BL_BOOT | Button_Switch_SMD:SW_SPST_TL3342 | 1 | ['SW3']
USB-A_1 | Connector_USB:USB_A_Stewart_SS-52100-001_Horizontal | 1 | ['J4']
500mA | Fuse:Fuse_1812_4532Metric | 4 | ['F2', 'F5', 'F3', 'F4']
0R | Resistor_SMD:R_0603_1608Metric | 1 | ['R20']
USB-C_2 | Connector_USB:USB_C_Receptacle_HRO_TYPE-C-31-M-12 | 1 | ['J7']
LED4 | LED_SMD:LED_0603_1608Metric | 1 | ['D8']
USBLC6-2SC6 | Package_TO_SOT_SMD:SOT-23-6 | 4 | ['U7', 'U6', 'U9', 'U8']
USB-C_1 | Connector_USB:USB_C_Receptacle_HRO_TYPE-C-31-M-12 | 1 | ['J6']
2k7 1% | Resistor_SMD:R_0603_1608Metric | 1 | ['R18']
LED0 | LED_SMD:LED_0603_1608Metric | 1 | ['D4']
WS2812_STRIP | Connector_JST:JST_XH_B3B-XH-A_1x03_P2.50mm_Vertical | 1 | ['J8']
USB-A_2 | Connector_USB:USB_A_Stewart_SS-52100-001_Horizontal | 1 | ['J5']
USB-C_POWER | Connector_USB:USB_C_Receptacle_HRO_TYPE-C-31-M-12 | 1 | ['J1']
1uF | Capacitor_SMD:C_0603_1608Metric | 1 | ['C9']
BL616_FLASH | Connector_PinHeader_2.54mm:PinHeader_1x04_P2.54mm_Vertical | 1 | ['J9']
ESP_FLASH | Connector_PinHeader_2.54mm:PinHeader_1x06_P2.54mm_Vertical | 1 | ['J2']
AMS1117-3.3 | Package_TO_SOT_SMD:SOT-223-3_TabPin2 | 2 | ['U2', 'U1']
ESP_UART_LINK | Connector_PinHeader_2.54mm:PinHeader_2x02_P2.54mm_Vertical | 1 | ['J3']
2k2 | Resistor_SMD:R_0603_1608Metric | 1 | ['R3']
ESP32-C6-WROOM-1-N8 | msxnano_dock:ESP32-C6-WROOM-1 | 1 | ['U3']
Sipeed_M0S_BL616 | msxnano_dock:M0S | 1 | ['U4']

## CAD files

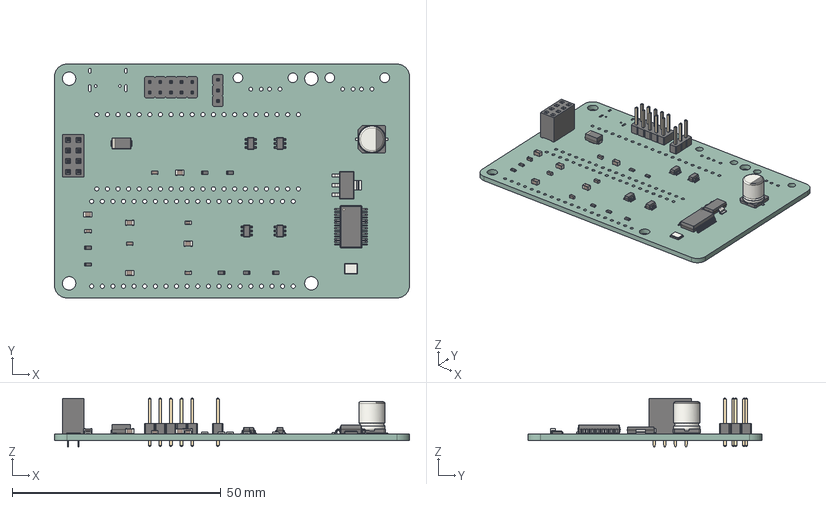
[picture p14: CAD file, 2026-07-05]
rpi3-compatible/board8020_rpi3.step
85.0 x 56.0 x 11.6 mm
R_0603_1608Metric x 7
C_0603_1608Metric x 5
SOT-23-6 x 4
C_0805_2012Metric x 5
CP_Elec_63x77
PinHeader_2x05_P254mm_Vertical
SOT-223
PinHeader_1x03_P254mm_Vertical
PinSocket_2x04_P2.54mm_Vertical
D_SMA
SSOP-28_5.3x10.2mm_P0.65mm
Crystal_SMD_3225-4Pin_3.2x2.5mm
msxnano-board8020_PCB

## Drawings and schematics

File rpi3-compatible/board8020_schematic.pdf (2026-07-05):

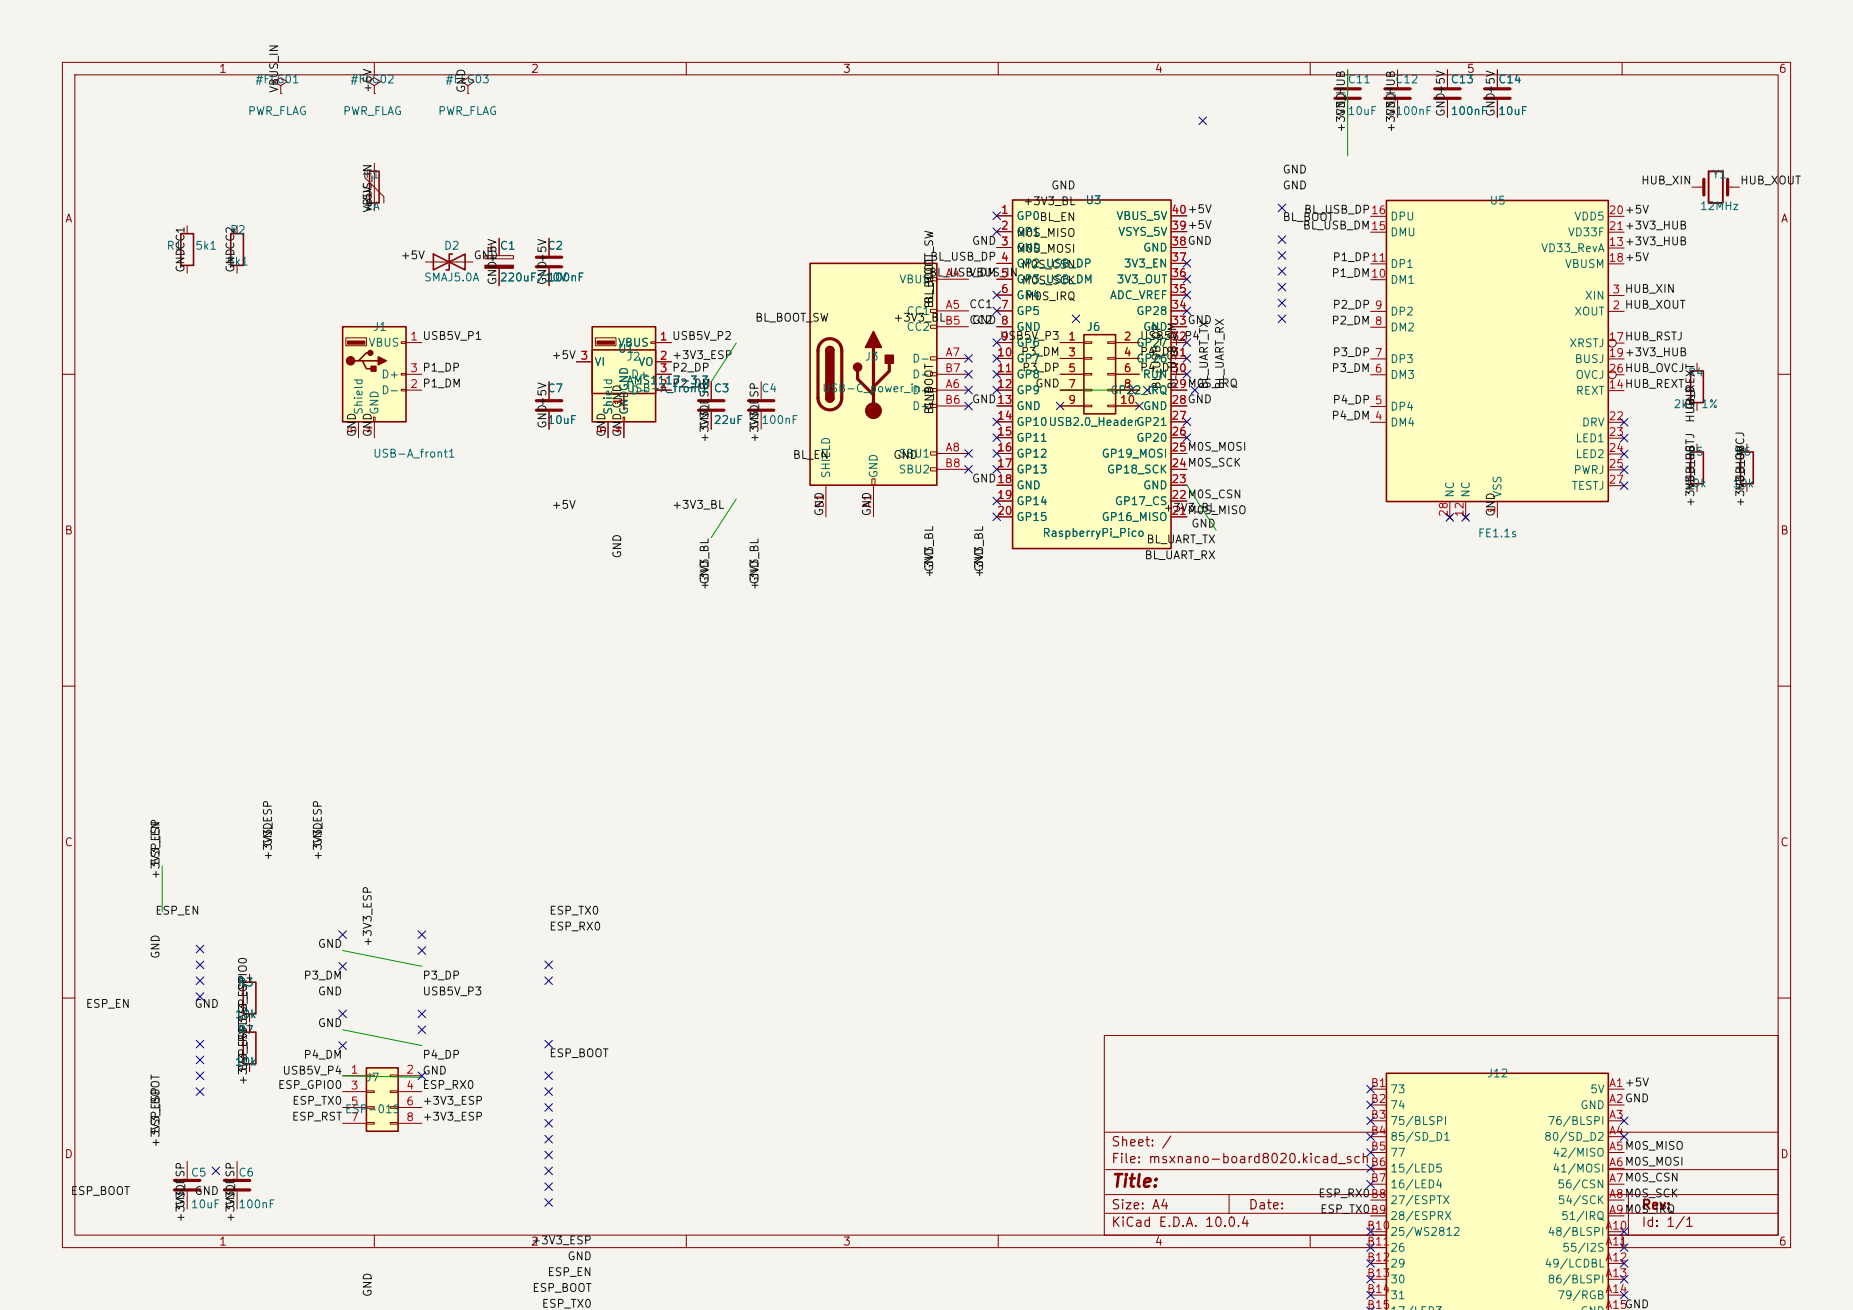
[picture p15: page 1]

Sheet: / File: msxnano-board8020.kicad_sch | 77 B5 42/MISO A5 15/LED5 B6 41/MOSI A6 | | D Date:

Title: | 16/LED4 B7 56/CSN A7
Size: A4 | ESP_TX0 | 27/ESPTX B8 54/SCK A8 28/ESPRX B9 51/IRQ A9 | M0S_IRQ | Rev:

KiCad E.D.A. 10.0.4 | | 25/WS2812 B10 48/BLSPIA10 | | Id: 1/1

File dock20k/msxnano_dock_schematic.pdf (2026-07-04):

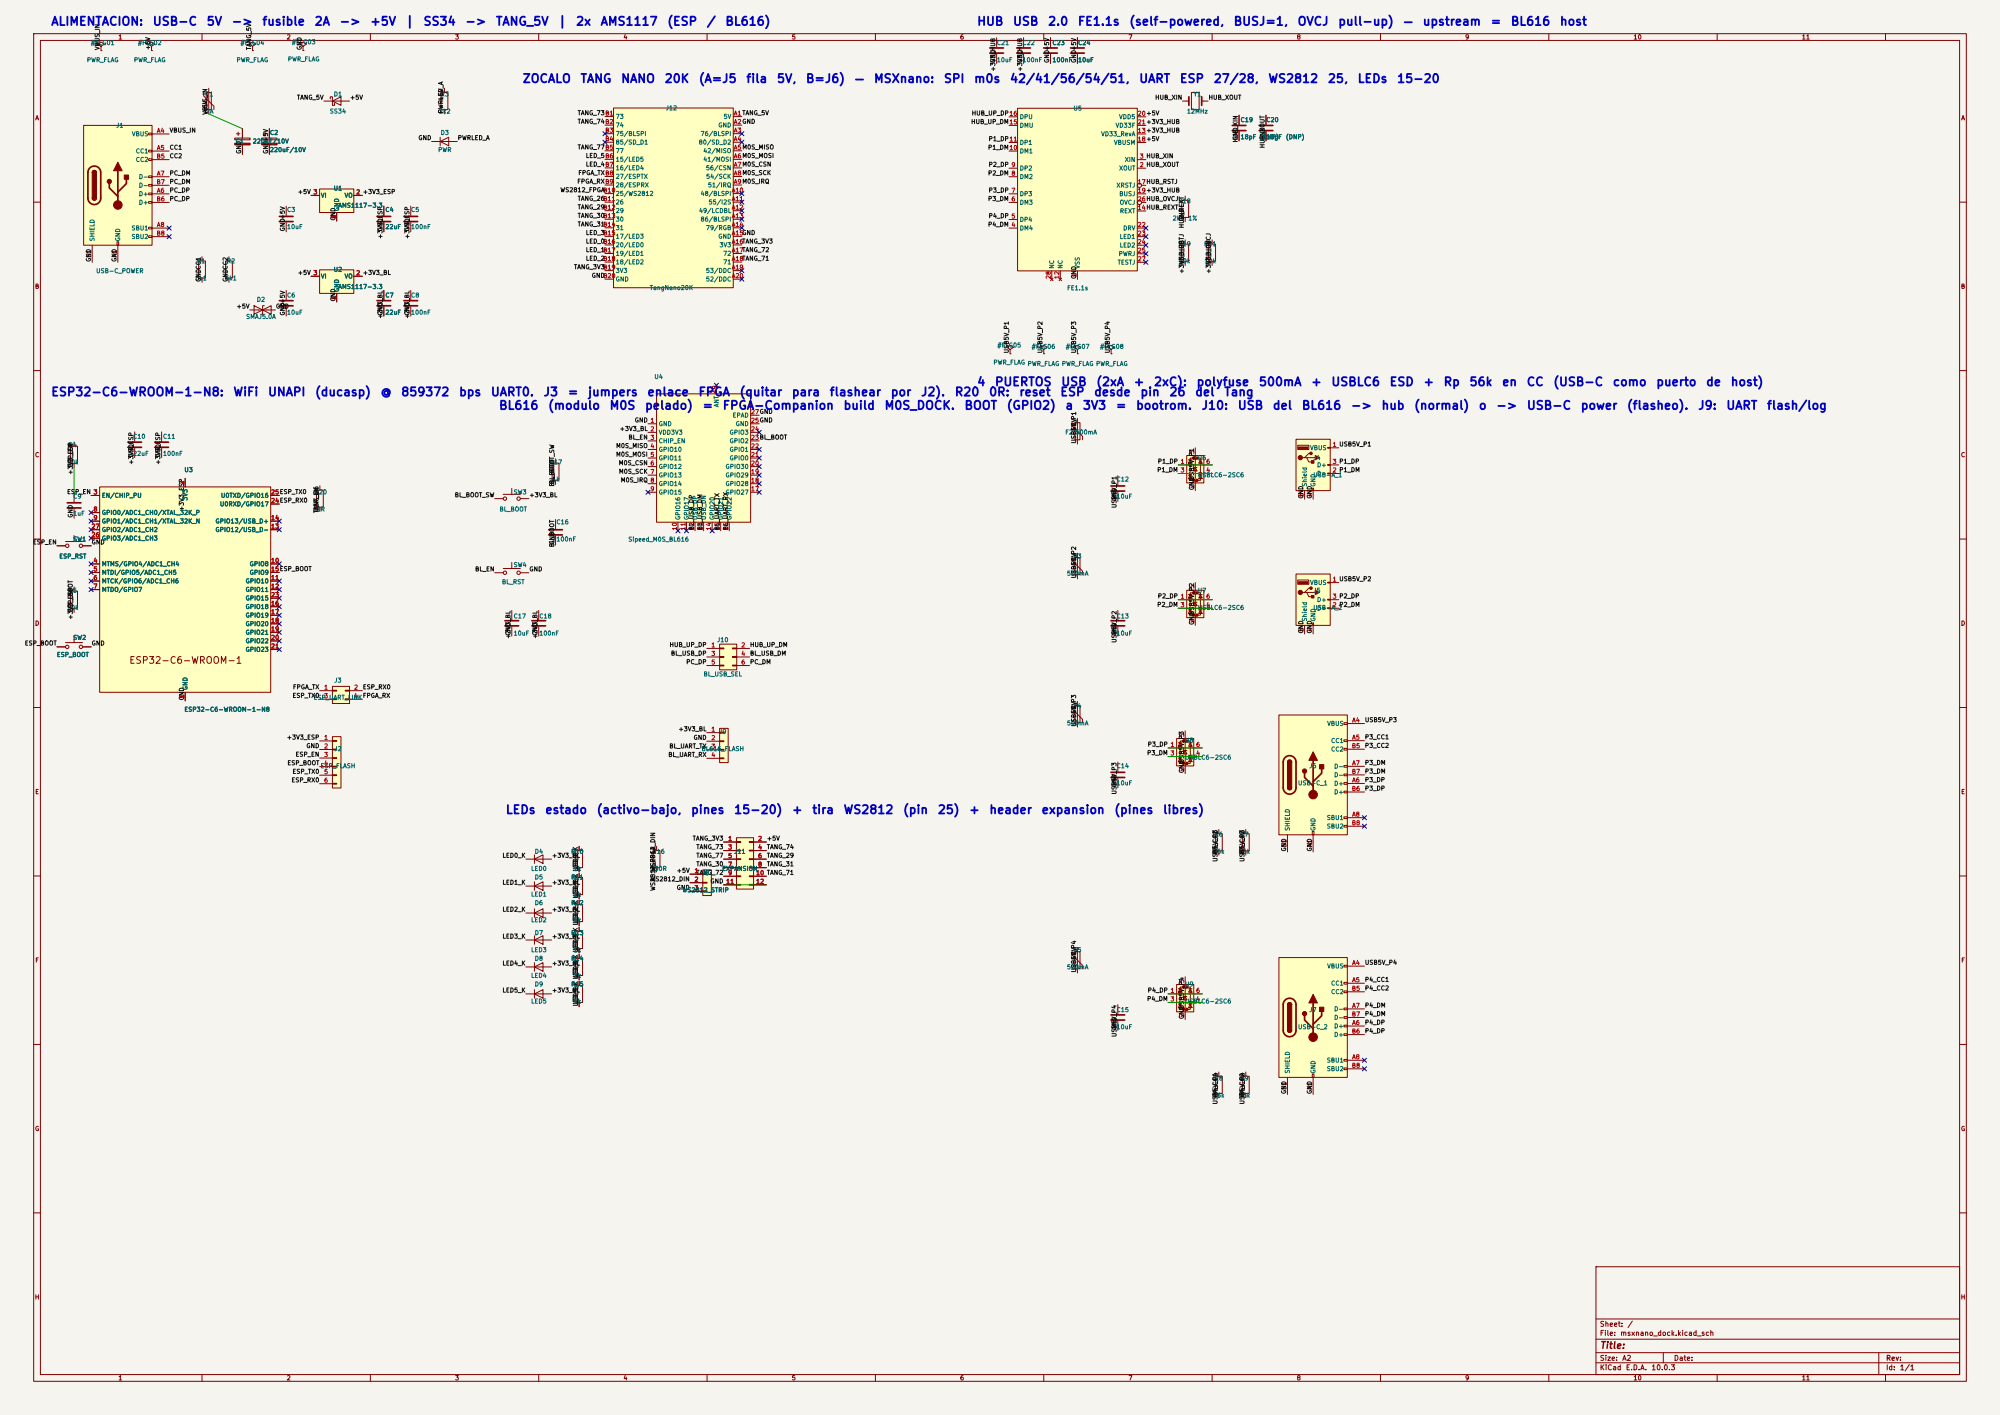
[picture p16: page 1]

ALIMENTACION: USB-C 5V -> fusible 2A -> +5V | SS34 -> TANG_5V | 2x AMS1117 (ESP / BL616)

HUB USB 2.0 FE1.1s (self-powered, BUSJ=1, OVCJ pull-up) — upstream = BL616 host
100nF VSS
TANG_5V LED5_K LED5_K

ZOCALO TANG NANO 20K (A=J5 fila 5V, B=J6) — MSXnano: SPI m0s 42/41/56/54/51, UART ESP 27/28, WS2812 25, LEDs 15-20

4 PUERTOS USB (2xA + 2xC): polyfuse 500mA + USBLC6 ESD + Rp 56k en CC (USB-C como puerto de host)

ESP32-C6-WROOM-1-N8: WiFi UNAPI (ducasp) @ 859372 bps UART0. J3 = jumpers enlace FPGA (quitar para flashear por J2). R20 0R: reset ESP desde pin 26 del Tang

BL616 (modulo M0S pelado) = FPGA-Companion build M0S_DOCK. BOOT (GPIO2) a 3V3 = bootrom. J10: USB del BL616 -> hub (normal) o -> USB-C power (flasheo). J9: UART flash/log

LEDs estado (activo-bajo, pines 15-20) + tira WS2812 (pin 25) + header expansion (pines libres)

Size: A2 | Rev:
KiCad E.D.A. 10.0.3 | Id: 1/1

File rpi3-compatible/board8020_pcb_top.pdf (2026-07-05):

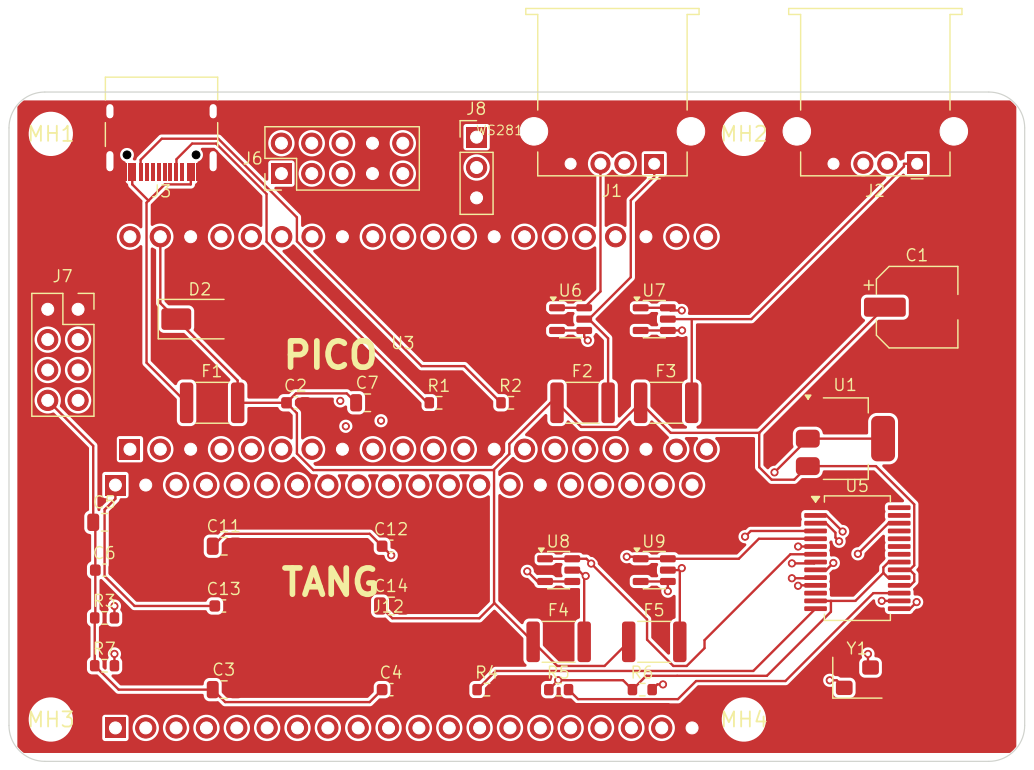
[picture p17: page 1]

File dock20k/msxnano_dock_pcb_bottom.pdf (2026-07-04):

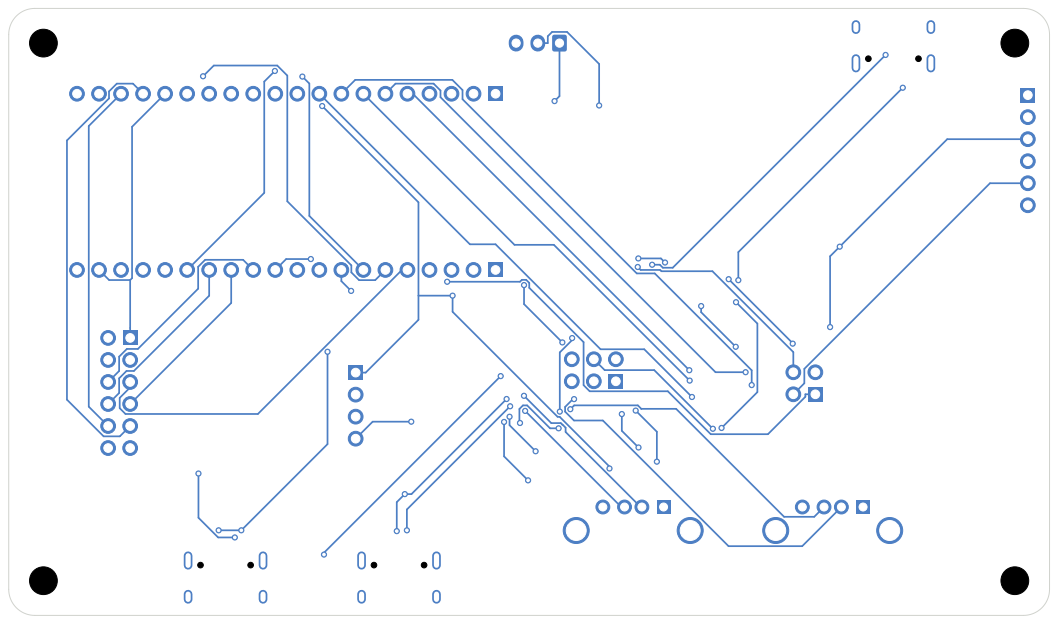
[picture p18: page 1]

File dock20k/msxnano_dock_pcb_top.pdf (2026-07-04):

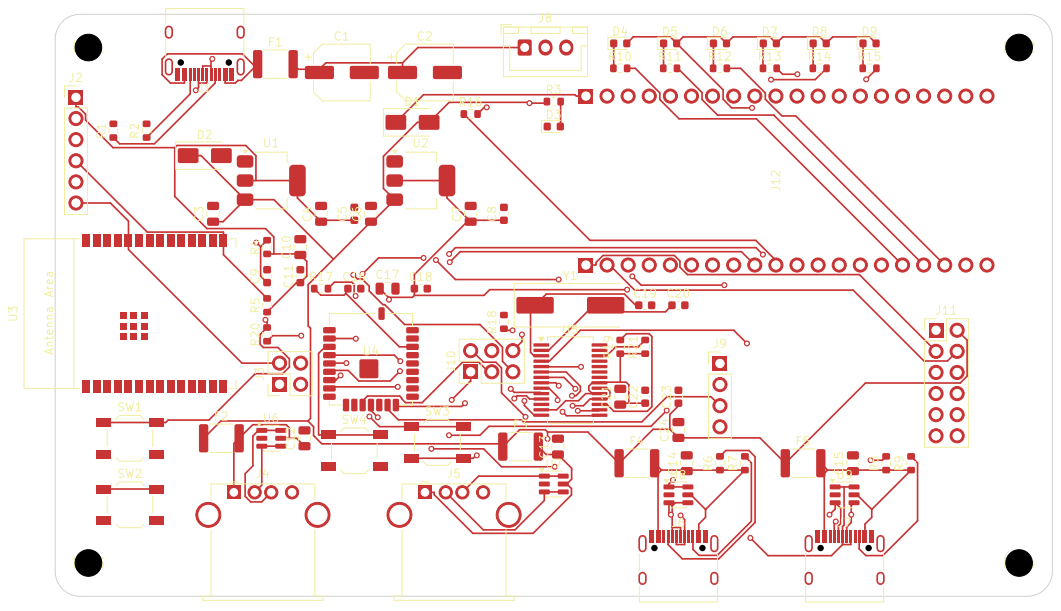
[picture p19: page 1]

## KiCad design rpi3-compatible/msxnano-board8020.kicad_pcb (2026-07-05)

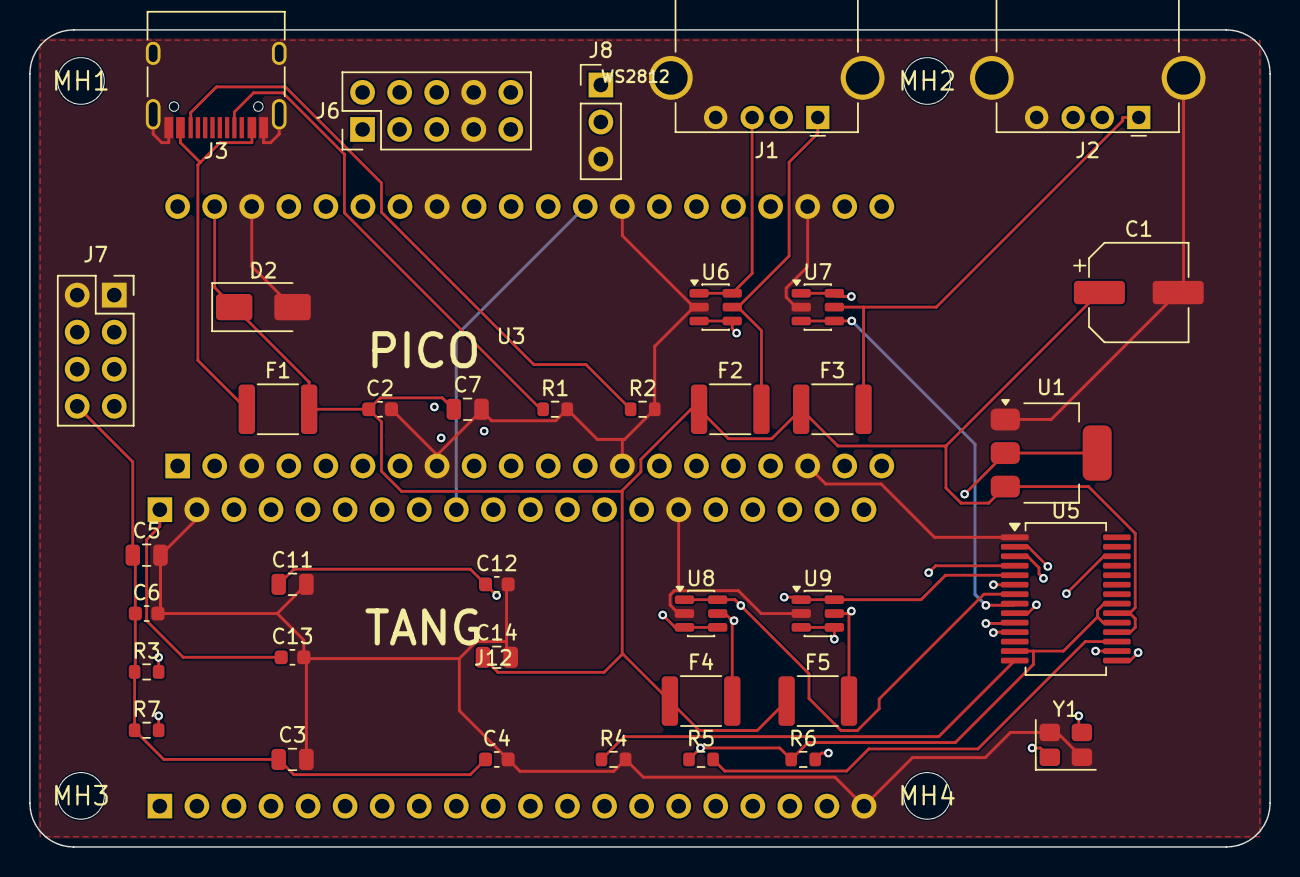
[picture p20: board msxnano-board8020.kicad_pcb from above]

Board: 4 copper layers, 85.0 x 56.0 mm, 43 parts (0 on the bottom side), 37 nets.

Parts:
C1: 220uF/10V; CP_Elec_6.3x7.7
C2, C4, C6, C12, C13: 100nF; C_0603_1608Metric
C3: 22uF; C_0805_2012Metric
C5, C7, C11, C14: 10uF; C_0805_2012Metric
D2: SMAJ5.0A; D_SMA
F1: 2A; Fuse_1812_4532Metric
F2, F3, F4, F5: 500mA; Fuse_1812_4532Metric
J1: USB-A_front1; USB_A_Stewart_SS-52100-001_Horizontal
J2: USB-A_front2; USB_A_Stewart_SS-52100-001_Horizontal
J3: USB-C_power_in; USB_C_Receptacle_HRO_TYPE-C-31-M-12
J6: USB2.0_Header; PinHeader_2x05_P2.54mm_Vertical
J7: ESP-01S; PinSocket_2x04_P2.54mm_Vertical
J8: WS2812; PinHeader_1x03_P2.54mm_Vertical
J12: TangNano20K; TangNano20K_Socket
MH1, MH2, MH3, MH4: MountingHole_3.2mm
R1, R2: 5k1; R_0603_1608Metric
R3, R5, R6, R7: 10k; R_0603_1608Metric
R4: 2k7 1%; R_0603_1608Metric
U1: AMS1117-3.3; SOT-223-3_TabPin2
U3: RaspberryPi_Pico; RPi_Pico_Socket
U5: FE1.1s; SSOP-28_5.3x10.2mm_P0.65mm
U6, U7, U8, U9: USBLC6-2SC6; SOT-23-6
Y1: 12MHz; Crystal_SMD_3225-4Pin_3.2x2.5mm

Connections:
+3V3_ESP: C3.1, C4.1, C5.1, C6.1, J7.6, J7.8, R3.1, R7.1, U1.2
+3V3_HUB: C11.1, C12.1, R5.1, R6.1, U5.13, U5.19, U5.21
+5V: C1.1, C2.1, C7.1, C13.1, C14.1, D2.1, F1.2, F2.1, F3.1, F4.1, F5.1, J8.1, J12.A1, U1.3, U3.39, U3.40, U5.18, U5.20
BL_USB_DM: U3.5, U5.15
BL_USB_DP: U3.4, U5.16
CC1: J3.A5, R1.1
CC2: J3.B5, R2.1
ESP_GPIO0: J7.3, R3.2
ESP_RST: J7.7, R7.2
ESP_RX0: J7.4, J12.B8
ESP_TX0: J7.5, J12.B9
GND: C1.2, C2.2, C3.2, C4.2, C5.2, C6.2, C7.2, C11.2, C12.2, C13.2, C14.2, D2.2, J1.4, J1.5, J2.4, J2.5, J3.A1, J3.A12, J3.B1, J3.B12, J3.S1, J6.7, J6.8, J7.1, J7.2, J8.3, J12.A2, J12.A15, J12.B20, R1.2, R2.2, R4.2, U1.1, U3.3, U3.8, U3.13, U3.18, U3.23, U3.28, U3.33, U3.38, U5.1, U6.2, U7.2, U8.2, U9.2, Y1.2, Y1.4
HUB_OVCJ: R6.2, U5.26
HUB_REXT: R4.1, U5.14
HUB_RSTJ: R5.2, U5.17
HUB_XIN: U5.3, Y1.1
HUB_XOUT: U5.2, Y1.3
M0S_CSN: J12.A7, U3.22
M0S_IRQ: J12.A9, U3.29
M0S_MISO: J12.A5, U3.21
M0S_MOSI: J12.A6, U3.25
M0S_SCK: J12.A8, U3.24
P1_DM: J1.2, U5.10, U6.3, U6.4
P1_DP: J1.3, U5.11, U6.1, U6.6
P2_DM: J2.2, U5.8, U7.3, U7.4
P2_DP: J2.3, U5.9, U7.1, U7.6
P3_DM: J6.3, U5.6, U8.3, U8.4
P3_DP: J6.5, U5.7, U8.1, U8.6
P4_DM: J6.4, U5.4, U9.3, U9.4
P4_DP: J6.6, U5.5, U9.1, U9.6
TANG_3V3: J12.A16, J12.B19
USB5V_P1: F2.2, J1.1, U6.5
USB5V_P2: F3.2, J2.1, U7.5
USB5V_P3: F4.2, J6.1, U8.5
USB5V_P4: F5.2, J6.2, U9.5
VBUS_IN: F1.1, J3.A4, J3.A9, J3.B4, J3.B9
WS2812_DIN: J8.2, U3.26

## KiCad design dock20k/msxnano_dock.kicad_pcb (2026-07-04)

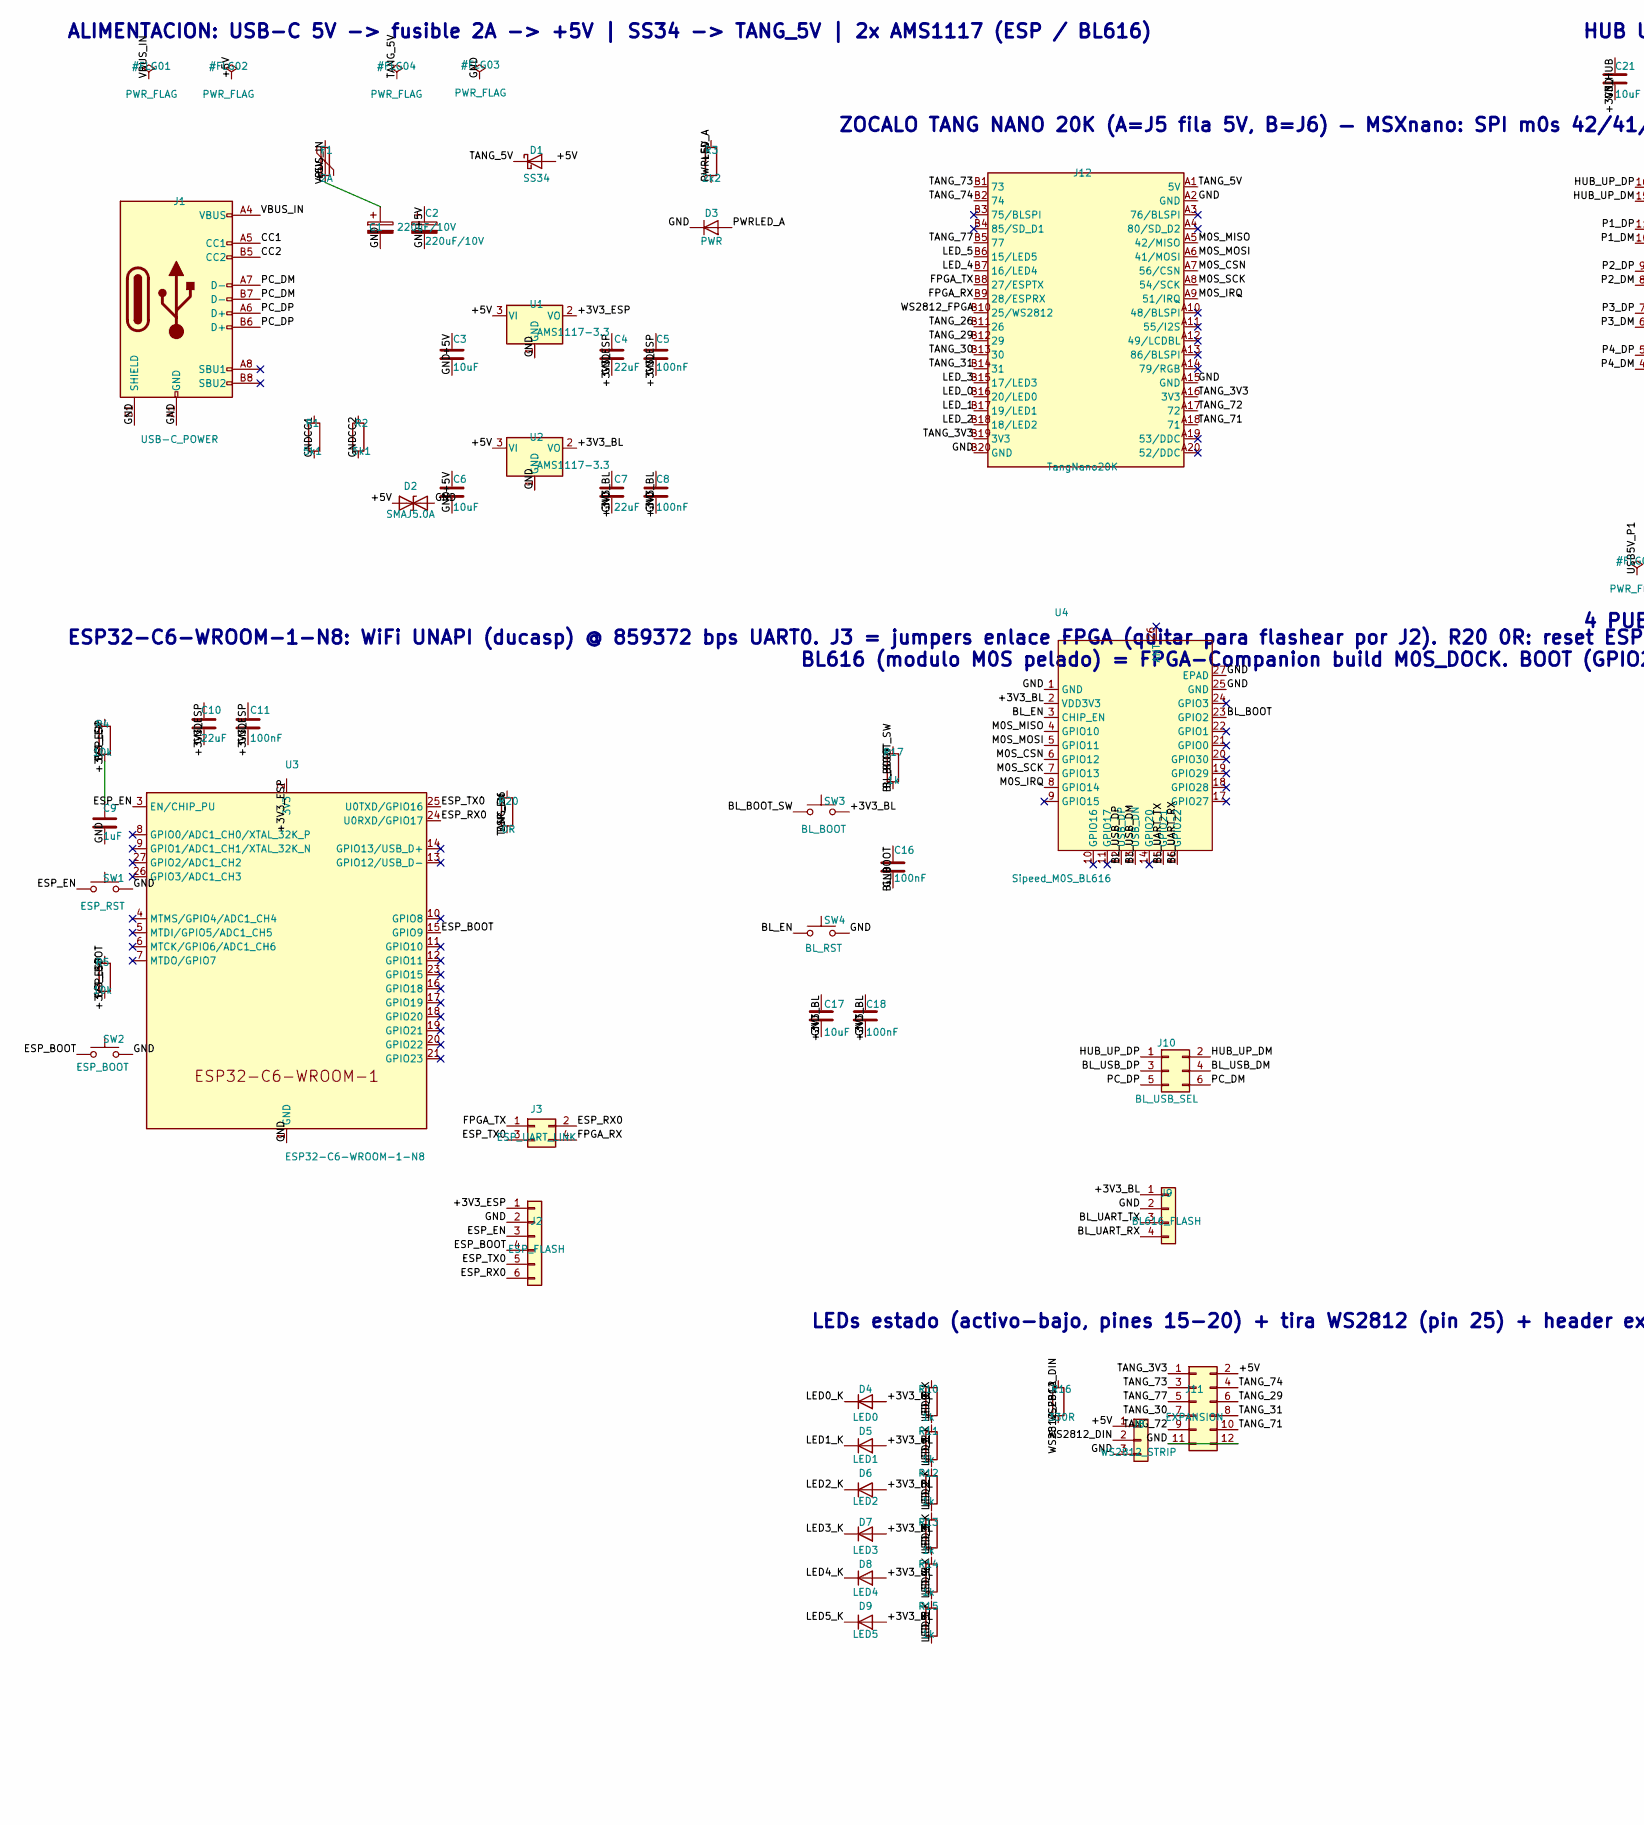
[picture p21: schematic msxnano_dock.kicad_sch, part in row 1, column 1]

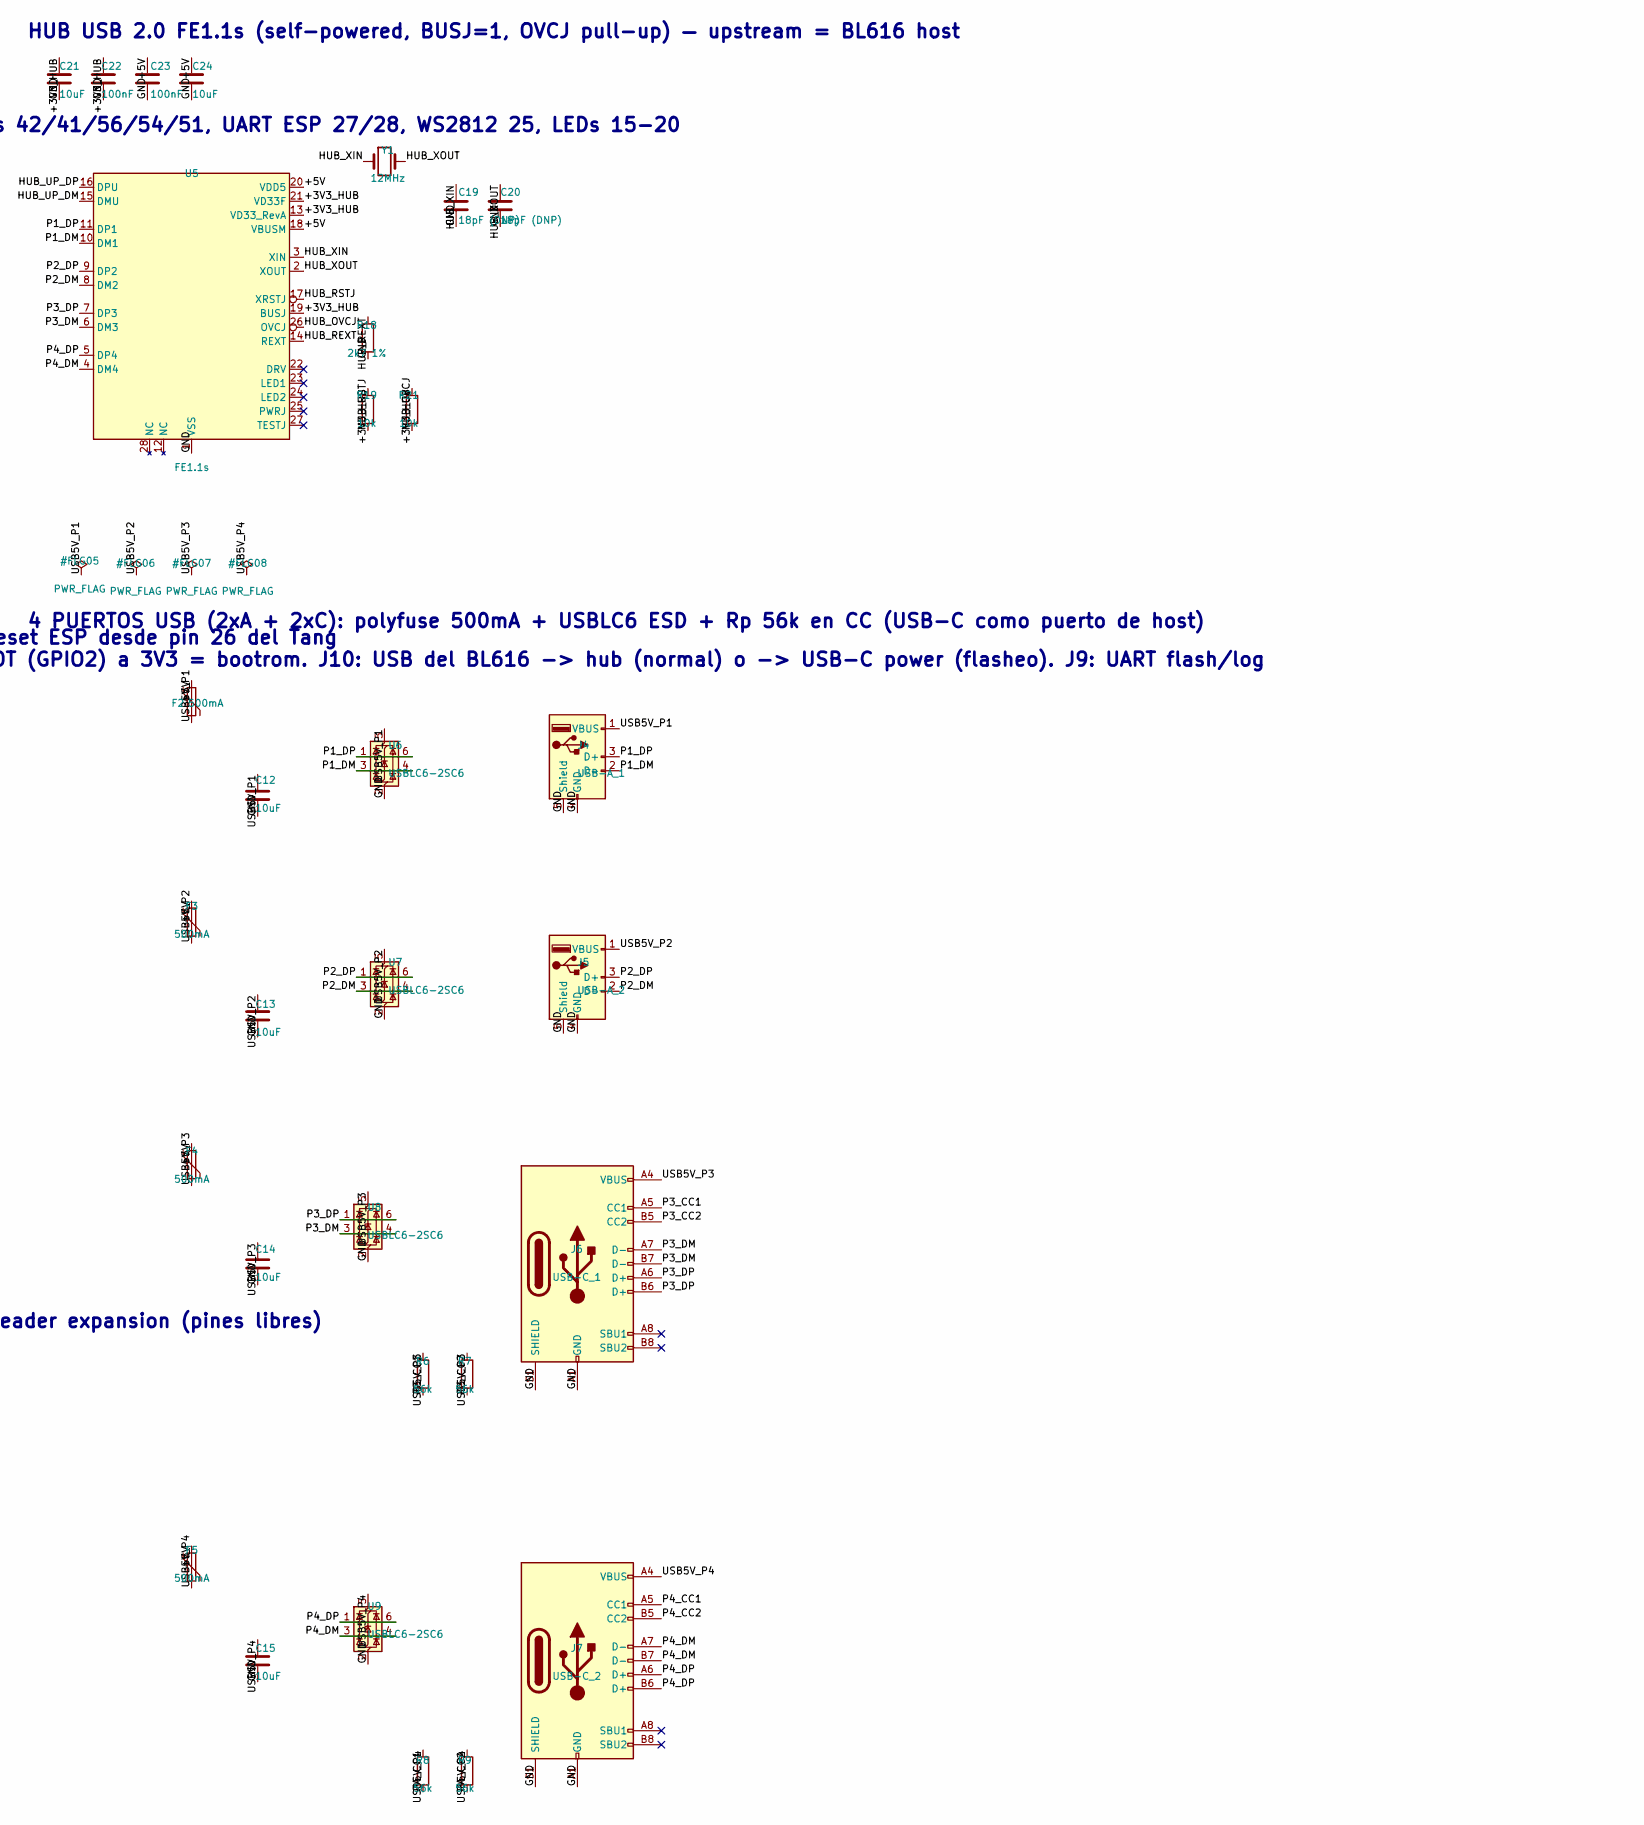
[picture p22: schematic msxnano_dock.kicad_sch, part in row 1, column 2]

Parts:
C1, C2: 220uF/10V; CP_Elec_6.3x7.7
C3, C6, C12, C13, C14, C15, C17, C21, C24: 10uF; C_0805_2012Metric
C4, C7, C10: 22uF; C_0805_2012Metric
C5, C8, C11, C16, C18, C22, C23: 100nF; C_0603_1608Metric
C9: 1uF; C_0603_1608Metric
C19, C20: 18pF (DNP); C_0603_1608Metric
D1: SS34; D_SMA
D2: SMAJ5.0A; D_SMA
D3: PWR; LED_0603_1608Metric
D4: LED0; LED_0603_1608Metric
D5: LED1; LED_0603_1608Metric
D6: LED2; LED_0603_1608Metric
D7: LED3; LED_0603_1608Metric
D8: LED4; LED_0603_1608Metric
D9: LED5; LED_0603_1608Metric
F1: 2A; Fuse_1812_4532Metric
F2, F3, F4, F5: 500mA; Fuse_1812_4532Metric
J1: USB-C_POWER; USB_C_Receptacle_HRO_TYPE-C-31-M-12
J2: ESP_FLASH; PinHeader_1x06_P2.54mm_Vertical
J3: ESP_UART_LINK; PinHeader_2x02_P2.54mm_Vertical
J4: USB-A_1; USB_A_Stewart_SS-52100-001_Horizontal
J5: USB-A_2; USB_A_Stewart_SS-52100-001_Horizontal
J6: USB-C_1; USB_C_Receptacle_HRO_TYPE-C-31-M-12
J7: USB-C_2; USB_C_Receptacle_HRO_TYPE-C-31-M-12
J8: WS2812_STRIP; JST_XH_B3B-XH-A_1x03_P2.50mm_Vertical
J9: BL616_FLASH; PinHeader_1x04_P2.54mm_Vertical
J10: BL_USB_SEL; PinHeader_2x03_P2.54mm_Vertical
J11: EXPANSION; PinHeader_2x06_P2.54mm_Vertical
J12: TangNano20K; TangNano20K_Socket
R1, R2: 5k1; R_0603_1608Metric
R3: 2k2; R_0603_1608Metric
R4, R5, R19, R21: 10k; R_0603_1608Metric
R6, R7, R8, R9: 56k; R_0603_1608Metric
R10, R11, R12, R13, R14, R15, R17: 1k; R_0603_1608Metric
R16: 330R; R_0603_1608Metric
R18: 2k7 1%; R_0603_1608Metric
R20: 0R; R_0603_1608Metric
SW1: ESP_RST; SW_SPST_TL3342
SW2: ESP_BOOT; SW_SPST_TL3342
SW3: BL_BOOT; SW_SPST_TL3342
SW4: BL_RST; SW_SPST_TL3342
U1, U2: AMS1117-3.3; SOT-223-3_TabPin2
U3: ESP32-C6-WROOM-1-N8; ESP32-C6-WROOM-1
U4: Sipeed_M0S_BL616; M0S
U5: FE1.1s; SSOP-28_5.3x10.2mm_P0.65mm
U6, U7, U8, U9: USBLC6-2SC6; SOT-23-6
Y1: 12MHz; Crystal_SMD_HC49-SD

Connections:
+3V3_BL: C7.1, C8.1, C17.1, C18.1, D4.2 (A), D5.2 (A), D6.2 (A), D7.2 (A), D8.2 (A), D9.2 (A), J9.1, SW3.2, U2.2 (VO), U4.2 (VDD3V3)
+3V3_ESP: C4.1, C5.1, C10.1, C11.1, J2.1, R4.1, R5.1, U1.2 (VO), U3.2 (3V3)
+3V3_HUB: C21.1, C22.1, R19.1, R21.1, U5.13 (VD33_RevA), U5.19 (BUSJ), U5.21 (VD33F)
+5V: C1.1, C2.1, C3.1, C6.1, C23.1, C24.1, D1.2 (A), D2.1 (A1), F1.2, F2.1, F3.1, F4.1, F5.1, J8.1, J11.2, R3.1, U1.3 (VI), U2.3 (VI), U5.18 (VBUSM), U5.20 (VDD5)
BL_BOOT: C16.1, R17.1, U4.23 (GPIO2)
BL_BOOT_SW: R17.2, SW3.1
BL_EN: SW4.1, U4.3 (CHIP_EN)
BL_UART_RX: J9.4, U4.16 (GPIO22)
BL_UART_TX: J9.3, U4.15 (GPIO21)
BL_USB_DM: J10.4, U4.13 (USB_DN)
BL_USB_DP: J10.3, U4.12 (USB_DP)
CC1: J1.A5 (CC1), R1.1
CC2: J1.B5 (CC2), R2.1
ESP_BOOT: J2.4, R5.2, SW2.1, U3.15 (GPIO9)
ESP_EN: C9.1, J2.3, R4.2, R20.2, SW1.1, U3.3 (EN/CHIP_PU)
ESP_RX0: J2.6, J3.2, U3.24 (U0RXD/GPIO17)
ESP_TX0: J2.5, J3.3, U3.25 (U0TXD/GPIO16)
FPGA_RX: J3.4, J12.B9 (28/ESPRX)
FPGA_TX: J3.1, J12.B8 (27/ESPTX)
GND: C1.2, C2.2, C3.2, C4.2, C5.2, C6.2, C7.2, C8.2, C9.2, C10.2, C11.2, C12.2, C13.2, C14.2, C15.2, C16.2, C17.2, C18.2, C19.2, C20.2, C21.2, C22.2, C23.2, C24.2, D2.2 (A2), D3.1 (K), J1.A1 (GND), J1.A12 (GND), J1.B1 (GND), J1.B12 (GND), J1.S1 (SHIELD), J2.2, J4.4 (GND), J4.5 (Shield), J5.4 (GND), J5.5 (Shield), J6.A1 (GND), J6.A12 (GND), J6.B1 (GND), J6.B12 (GND), J6.S1 (SHIELD), J7.A1 (GND), J7.A12 (GND), J7.B1 (GND), J7.B12 (GND), J7.S1 (SHIELD), J8.3, J9.2, J11.11, J11.12, J12.A2 (GND), J12.A15 (GND), J12.B20 (GND), R1.2, R2.2, R18.2, SW1.2, SW2.2, SW4.2, U1.1 (GND), U2.1 (GND), U3.1 (GND), U3.28 (GND), U3.29 (GND), U4.1 (GND), U4.25 (GND), U4.27 (EPAD), U5.1 (VSS), U6.2 (GND), U7.2 (GND), U8.2 (GND), U9.2 (GND)
HUB_OVCJ: R21.2, U5.26 (OVCJ)
HUB_REXT: R18.1, U5.14 (REXT)
HUB_RSTJ: R19.2, U5.17 (XRSTJ)
HUB_UP_DM: J10.2, U5.15 (DMU)
HUB_UP_DP: J10.1, U5.16 (DPU)
HUB_XIN: C19.1, U5.3 (XIN), Y1.1
HUB_XOUT: C20.1, U5.2 (XOUT), Y1.2
LED0_K: D4.1 (K), R10.1
LED1_K: D5.1 (K), R11.1
LED2_K: D6.1 (K), R12.1
LED3_K: D7.1 (K), R13.1
LED4_K: D8.1 (K), R14.1
LED5_K: D9.1 (K), R15.1
LED_0: J12.B16 (20/LED0), R10.2
LED_1: J12.B17 (19/LED1), R11.2
LED_2: J12.B18 (18/LED2), R12.2
LED_3: J12.B15 (17/LED3), R13.2
LED_4: J12.B7 (16/LED4), R14.2
LED_5: J12.B6 (15/LED5), R15.2
M0S_CSN: J12.A7 (56/CSN), U4.6 (GPIO12)
M0S_IRQ: J12.A9 (51/IRQ), U4.8 (GPIO14)
M0S_MISO: J12.A5 (42/MISO), U4.4 (GPIO10)
M0S_MOSI: J12.A6 (41/MOSI), U4.5 (GPIO11)
M0S_SCK: J12.A8 (54/SCK), U4.7 (GPIO13)
P1_DM: J4.2 (D-), U5.10 (DM1), U6.3 (I/O2), U6.4 (I/O2)
P1_DP: J4.3 (D+), U5.11 (DP1), U6.1 (I/O1), U6.6 (I/O1)
P2_DM: J5.2 (D-), U5.8 (DM2), U7.3 (I/O2), U7.4 (I/O2)
P2_DP: J5.3 (D+), U5.9 (DP2), U7.1 (I/O1), U7.6 (I/O1)
P3_CC1: J6.A5 (CC1), R6.2
P3_CC2: J6.B5 (CC2), R7.2
P3_DM: J6.A7 (D-), J6.B7 (D-), U5.6 (DM3), U8.3 (I/O2), U8.4 (I/O2)
P3_DP: J6.A6 (D+), J6.B6 (D+), U5.7 (DP3), U8.1 (I/O1), U8.6 (I/O1)
P4_CC1: J7.A5 (CC1), R8.2
P4_CC2: J7.B5 (CC2), R9.2
P4_DM: J7.A7 (D-), J7.B7 (D-), U5.4 (DM4), U9.3 (I/O2), U9.4 (I/O2)
P4_DP: J7.A6 (D+), J7.B6 (D+), U5.5 (DP4), U9.1 (I/O1), U9.6 (I/O1)
PC_DM: J1.A7 (D-), J1.B7 (D-), J10.6
PC_DP: J1.A6 (D+), J1.B6 (D+), J10.5
PWRLED_A: D3.2 (A), R3.2
TANG_3V3: J11.1, J12.A16 (3V3), J12.B19 (3V3)
TANG_5V: D1.1 (K), J12.A1 (5V)
TANG_26: J12.B11 (26), R20.1
TANG_29: J11.6, J12.B12 (29)
TANG_30: J11.7, J12.B13 (30)
TANG_31: J11.8, J12.B14 (31)
TANG_71: J11.10, J12.A18 (71)
TANG_72: J11.9, J12.A17 (72)
TANG_73: J11.3, J12.B1 (73)
TANG_74: J11.4, J12.B2 (74)
TANG_77: J11.5, J12.B5 (77)
USB5V_P1: C12.1, F2.2, J4.1 (VBUS), U6.5 (VBUS)
USB5V_P2: C13.1, F3.2, J5.1 (VBUS), U7.5 (VBUS)
USB5V_P3: C14.1, F4.2, J6.A4 (VBUS), J6.A9 (VBUS), J6.B4 (VBUS), J6.B9 (VBUS), R6.1, R7.1, U8.5 (VBUS)
USB5V_P4: C15.1, F5.2, J7.A4 (VBUS), J7.A9 (VBUS), J7.B4 (VBUS), J7.B9 (VBUS), R8.1, R9.1, U9.5 (VBUS)
VBUS_IN: F1.1, J1.A4 (VBUS), J1.A9 (VBUS), J1.B4 (VBUS), J1.B9 (VBUS)
WS2812_DIN: J8.2, R16.2
WS2812_FPGA: J12.B10 (25/WS2812), R16.1

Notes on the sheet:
ALIMENTACION: USB-C 5V -> fusible 2A -> +5V | SS34 -> TANG_5V | 2x AMS1117 (ESP / BL616)
ZOCALO TANG NANO 20K (A=J5 fila 5V, B=J6) — MSXnano: SPI m0s 42/41/56/54/51, UART ESP 27/28, WS2812 25, LEDs 15-20
HUB USB 2.0 FE1.1s (self-powered, BUSJ=1, OVCJ pull-up) — upstream = BL616 host
ESP32-C6-WROOM-1-N8: WiFi UNAPI (ducasp) @ 859372 bps UART0. J3 = jumpers enlace FPGA (quitar para flashear por J2). R20 0R: reset ESP desde pin 26 del Tang
BL616 (modulo M0S pelado) = FPGA-Companion build M0S_DOCK. BOOT (GPIO2) a 3V3 = bootrom. J10: USB del BL616 -> hub (normal) o -> USB-C power (flasheo). J9: UART flash/log
4 PUERTOS USB (2xA + 2xC): polyfuse 500mA + USBLC6 ESD + Rp 56k en CC (USB-C como puerto de host)
LEDs estado (activo-bajo, pines 15-20) + tira WS2812 (pin 25) + header expansion (pines libres)

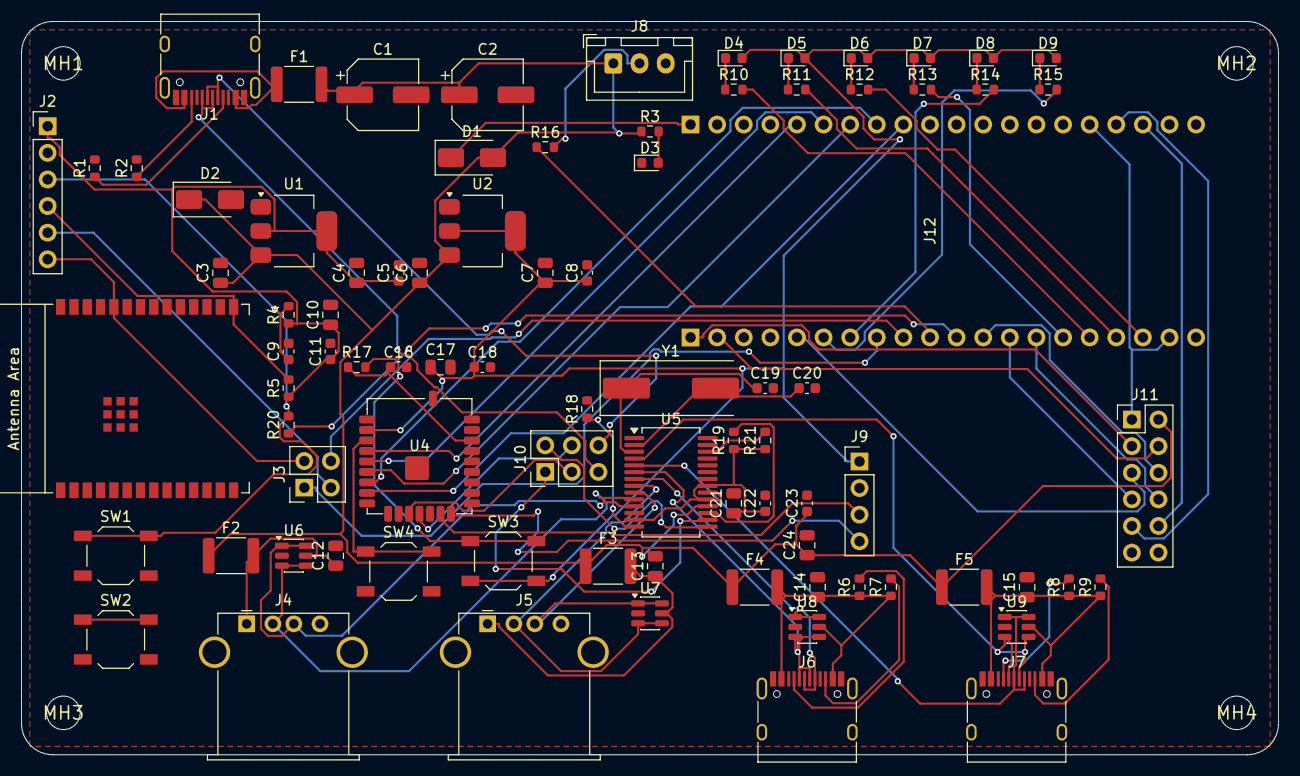
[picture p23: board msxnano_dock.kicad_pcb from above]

Board: 2 copper layers, 120.0 x 70.0 mm, 89 parts (0 on the bottom side), 77 nets.

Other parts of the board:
MH1, MH2, MH3, MH4: MountingHole_3.2mm

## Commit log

2026-07-04 dock20k: proof-of-concept M0S carrier board for Tang Nano 20K
    Integrates an M0S (BL616) USB companion + FE1.1s 4-port USB hub
    (2x USB-A + 2x USB-C) + ESP32-C6 WiFi (UNAPI) on a Tang Nano 20K
    carrier, so the USB keyboard works on locked '3921' boards without
    an external dock and everything runs through the Tang's headers.
    Schematic (ERC 0), routed 2-layer PCB (DRC 0), bilingual docs (ES/EN),
    HTML readme and 3D renders.
    [msxnano_dock.kicad_pcb, msxnano_dock.kicad_sch, msxnano_dock_bom.csv]
2026-07-04 dock20k: add render + KiCad layout gallery
    Extra concept views: top-down 3D board shot, low-angle assembled
    (Tang on its socket), front elevation of the stack, and 2D top/bottom
    copper straight from KiCad (the routing). Added a gallery to the
    bilingual README (md + html).
2026-07-04 Remove stray ruvector.db (tool artifact, not part of the board); ignore *.db
2026-07-05 rpi3-compatible: add RPi3 form-factor carrier (Pico + ESP-01S + FE1.1s hub)
    85x56mm 4-layer, fully modular (plug-in Raspberry Pi Pico USB companion +
    ESP-01S WiFi, no soldered BL616). Routed 100% (DRC 0 electrical errors),
    GND planes on all 4 layers. Includes JLCPCB fab package: gerbers + BOM +
    CPL (rotation-corrected), STEP, schematic/PCB PDFs. Not fabricated yet.
    [board8020_BOM_jlcpcb.csv, board8020_rpi3.step, msxnano-board8020.kicad_pcb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]
